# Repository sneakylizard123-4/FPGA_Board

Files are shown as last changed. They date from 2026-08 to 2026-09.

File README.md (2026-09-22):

# FPGA_Board

A iCE40 FPGA devboard

## Custom Features
- ICE40UP5K-SG48ITR FPGA (5280 LUTs, QFN-48)
- On-board FT232H flasher with EEPROM
- 16MB W25Q128JVS SPI flash
- USB-C with ESD protection
- RGB LED, green config-status LED, reset button
- 12MHz oscillator, 4-layer PCB

## PCB Design

The board is a 4-layer PCB.

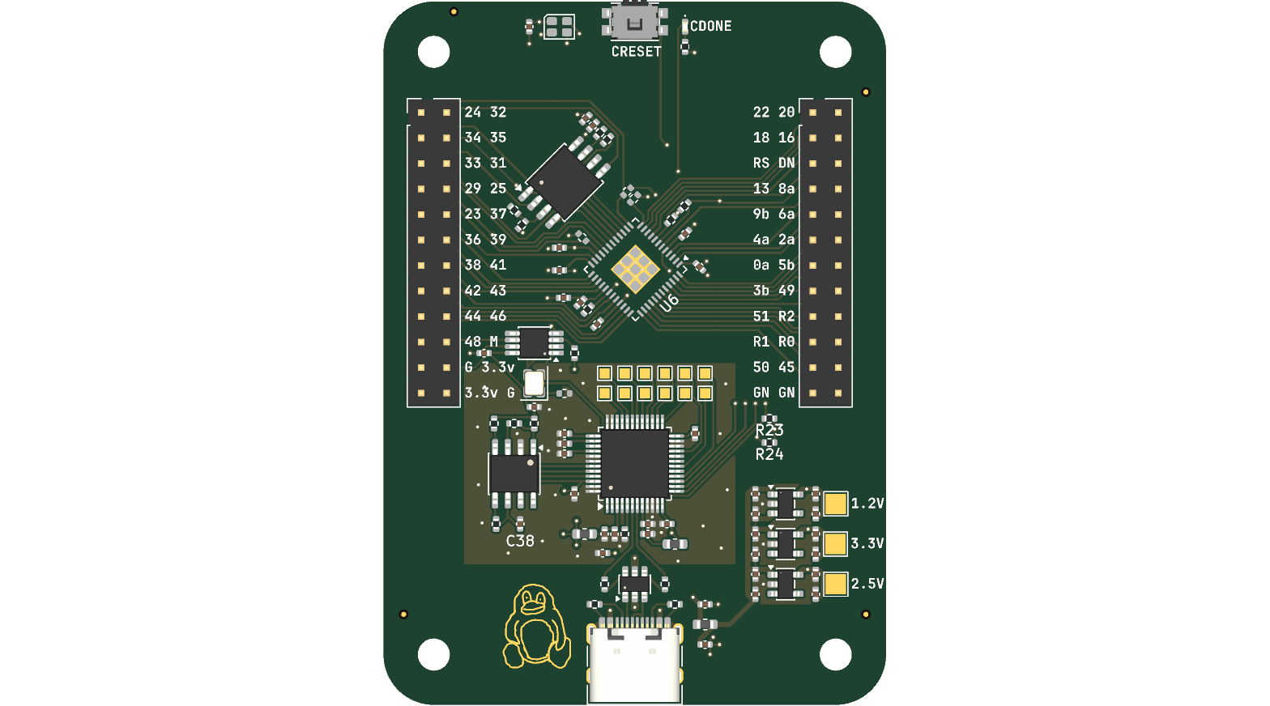
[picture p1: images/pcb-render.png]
PCB 3D / layout image


It is built around the Lattice iCE40 FPGA, designed to be programmed over USB through the on-board FT232H. The SPI flash boots the bitstream on power-up.
It is fully supported by the open-source yosys/nextpnr/icestorm flow.

## Firmware

As the board uses an iCE40 UltraPlus, it is programmed with yosys + nextpnr-ice40 + icepack + iceprog/icestorm.

## BOM

| Ref | Value | LCSC # | MPN | Manufacturer | Footprint | Qty | Unit $ | Ext $ | Link |
|-----|---|---|-----|---|---|-----|---|---|---|
| C1,C2,C3,C4,C5,C12,C13,C14,C17,C24,C34,C35 | 10uF 0402 | C307415 | - | - | 0402 | 12 | 0.1900 | 2.28 | [LCSC](https://www.lcsc.com/product-detail/C307415.html) |
| C6,C7,C8,C9,C10,C11,C15,C16,C18,C19,C20,C21,C22,C23,C25,C26,C27,C28,C29,C30,C31,C32,C33,C37,C38 | 100nF 0402 | C131394 | - | - | 0402 | 25 | 0.0096 | 0.24 | [LCSC](https://www.lcsc.com/product-detail/C131394.html) |
| C36 | 4.7uF 0402 | C21120 | - | - | 0402 | 1 | 0.0200 | 0.02 | [LCSC](https://www.lcsc.com/product-detail/C21120.html) |
| D1 | LED_ARGB PLCC4 | C2786 | - | - | LED_Cree-PLCC4_2x2mm_CW | 1 | 0.1300 | 0.13 | [LCSC](https://www.lcsc.com/product-detail/C2786.html) |
| D2 | Green LED 0402 | C2286 | - | - | 0402 | 1 | 0.0100 | 0.01 | [LCSC](https://www.lcsc.com/product-detail/C2286.html) |
| FB1,FB2,FB3 | Ferrite Bead 1.5k | C82155 | BLM18HE152SN1D | muRata | 0603 | 3 | 0.0300 | 0.09 | [LCSC](https://www.lcsc.com/product-detail/C82155.html) |
| J1 | USB-C Receptacle 14P | C165948 | TYPE-C-31-M-12 | Korean Hroparts Elec | USB-C | 1 | 0.1900 | 0.19 | [LCSC](https://www.lcsc.com/product-detail/C165948.html) |
| J3,J4 | Pin Header 2x12 2.54mm | C492423 | PZ254V-12-12P | XFCN | Through Hole | 2 | 0.0700 | 0.14 | [LCSC](https://www.lcsc.com/product-detail/C492423.html) |
| R1,R2 | 5.1k 1% 0402 | C25905 | 0402WGF5101TCE | UNI-ROYAL | 0402 | 2 | 0.0040 | 0.01 | [LCSC](https://www.lcsc.com/product-detail/C25905.html) |
| R3,R4 | 22R 1% 0402 | C23200 | - | - | 0402 | 2 | 0.0040 | 0.01 | [LCSC](https://www.lcsc.com/product-detail/C23200.html) |
| R5,R6,R10,R11,R19,R20,R21,R23,R24 | 10k 1% 0402 | C25904 | - | - | 0402 | 9 | 0.0040 | 0.04 | [LCSC](https://www.lcsc.com/product-detail/C25904.html) |
| R7 | 1k 1% 0402 | C25898 | - | - | 0402 | 1 | 0.0040 | 0.00 | [LCSC](https://www.lcsc.com/product-detail/C25898.html) |
| R8,R9,R14 | 0R 0402 | C25887 | - | - | 0402 | 3 | 0.0030 | 0.01 | [LCSC](https://www.lcsc.com/product-detail/C25887.html) |
| R12 | 100R 1% 0402 | C22861 | - | - | 0402 | 1 | 0.0040 | 0.00 | [LCSC](https://www.lcsc.com/product-detail/C22861.html) |
| R18 | 12k 1% 0402 | C25913 | - | - | 0402 | 1 | 0.0040 | 0.00 | [LCSC](https://www.lcsc.com/product-detail/C25913.html) |
| R22 | 2.2k 1% 0402 | C25901 | - | - | 0402 | 1 | 0.0040 | 0.00 | [LCSC](https://www.lcsc.com/product-detail/C25901.html) |
| SW1 | Tactile Switch EVQPUD | C158289 | EVQPUM | PANASONIC | SMD | 1 | 0.2000 | 0.20 | [LCSC](https://www.lcsc.com/product-detail/C158289.html) |
| U1 | USBLC6-2SC6 | C7519 | USBLC6-2SC6 | ST | SOT-23-6 | 1 | 0.1800 | 0.18 | [LCSC](https://www.lcsc.com/product-detail/C7519.html) |
| U2 | TLV75712PDBV | C485515 | TLV75712PDBVR | TI | SOT-23-5 | 1 | 0.1800 | 0.18 | [LCSC](https://www.lcsc.com/product-detail/C485515.html) |
| U3 | TLV75725PDBV | C485516 | TLV75725PDBVR | TI | SOT-23-5 | 1 | 0.1800 | 0.18 | [LCSC](https://www.lcsc.com/product-detail/C485516.html) |
| U4 | TLV75733PDBV | C485517 | TLV75733PDBVR | TI | SOT-23-5 | 1 | 0.1800 | 0.18 | [LCSC](https://www.lcsc.com/product-detail/C485517.html) |
| U5 | 74AUC2G240 | C2652105 | - | - | VSSOP-8 | 1 | 0.7200 | 0.72 | [LCSC](https://www.lcsc.com/product-detail/C2652105.html) |
| U6 | ICE40UP5K-SG48ITR | C2678152 | ICE40UP5K-SG48ITR | Lattice | QFN-48 | 1 | 8.5600 | 8.56 | [LCSC](https://www.lcsc.com/product-detail/C2678152.html) |
| U7 | W25Q128JVS | C113767 | W25Q128JVS | Winbond | SOIC-8 | 1 | 2.5200 | 2.52 | [LCSC](https://www.lcsc.com/product-detail/C113767.html) |
| U8 | FT232H | C51997 | FT232HL | FTDI | LQFP-48 | 1 | 10.6200 | 10.62 | [LCSC](https://www.lcsc.com/product-detail/C51997.html) |
| U9 | 93LC56BT-I/OT | C190271 | 93LC56BT-I/OT | Microchip | SOIC-8 | 1 | 0.4500 | 0.45 | [LCSC](https://www.lcsc.com/product-detail/C190271.html) |
| Y1 | SG-210STF 12MHz | C17426037 | SG-210STF | Seiko Epson | 2.5x2.0mm | 1 | 0.3700 | 0.37 | [LCSC](https://www.lcsc.com/product-detail/C17426037.html) |
| PCB | Bare PCB | — | — | — | 50x70mm | 1 | 20.0000 | 20.00 | — |
| STENCIL | Top stencil | — | — | — | 100x150mm | 1 | 18.0000 | 18.00 | — |
| **Total** | — | — | — | — | — | **79** | — | **65.33** | — |

Full CSVs: [LCSC BOM](BOM.csv)
[KiCad generated BOM](kicad/production/bom.csv)
[Pick and place](kicad/production/positions.csv)

## Production

Production files in [Prod Files](kicad/production/)
This board assumes JLCPCB's standard 4 layer
- HASL Lead Free
- 1.6mm thick board

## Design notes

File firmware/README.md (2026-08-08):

# FPGA_Board firmware (ICE40UP5K)

Open-source iceStorm flow: `yosys` -> `nextpnr-ice40` -> `icepack` -> `iceprog`.

## Proof-of-life: RGB rainbow

`rtl/rainbow.v` cycles the on-board common-anode RGB LED through the color
wheel. The hue advances 25x/second, so one lap takes 10 seconds.

## Pin map

| Signal | FPGA pin | Net | Note |
|---|---|---|---|
| clk_12m| 20 | IOB_25b_G3 | 12 MHz clock |
| rgb_r  | 39 | RGB0 | open-drain, active low |
| rgb_g  | 40 | RGB1 | open-drain, active low |
| rgb_b  | 41 | RGB2 | open-drain, active low |

The RGB LED (D1) is common-anode to 3.3 V, so its cathodes are driven
active-low directly by the FPGA. The green LED (D2) is wired to `CDONE`
(config-done indicator), not a user GPIO. SW1 pulls `CRESET` (pin 8) low.

## Build

```sh
make
```

## Program flash (iceprog)

```sh
make prog
```

`iceprog` uses the FT2232H via the SPI header (J3.2-5: FPGA_SO/FPGA_SI/
FT_SCK/FT_CS). After programming, toggle the FT_CS/MODE pins or press
SW1/cycle power to reconfigure from the W25Q128.

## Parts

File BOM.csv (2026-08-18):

Designator | Footprint | Quantity | Value | LCSC Part # | MOQ | Unit Price | Total Cost | Amount
C1, C2, C3, C4, C5, C12, C13, C14, C17, C24, C34, C35 | Capacitor_SMD:C_0402_1005Metric | 12 | 10uF | C307415 | 5 | $0.1900 | $2.28 | 12
C6, C7, C8, C9, C10, C11, C15, C16, C18, C19, C20, C21, C22, C23, C25, C26, C27, C28, C29, C30, C31, C32, C33, C37, C38 | Capacitor_SMD:C_0402_1005Metric | 25 | 0.1uF | C131394 | 100 | $0.0096 | $0.96 | 100
C36 | Capacitor_SMD:C_0402_1005Metric | 1 | 4.7uF | C21120 | 5 | $0.0200 | $0.10 | 5
D1 | LED_SMD:LED_Cree-PLCC4_2x2mm_CW | 1 | LED_ARGB | C2786 | 5 | $0.1300 | $0.65 | 5
D2 | LED_SMD:LED_0402_1005Metric | 1 | GREEN | C2286 | 5 | $0.0100 | $0.05 | 5
FB1, FB2, FB3 | Inductor_SMD:L_0603_1608Metric | 3 | BLM18HE152SN1D | C82155 | 10 | $0.0300 | $0.30 | 10
J1 | Connector_USB:USB_C_Receptacle_HRO_TYPE-C-31-M-12 | 1 | USB_C_Receptacle_USB2.0_14P | C165948 | 5 | $0.1900 | $0.95 | 5
J3, J4 | Connector_PinHeader_2.54mm:PinHeader_2x12_P2.54mm_Vertical | 2 | Conn_02x12_Odd_Even | C492423 | 10 | $0.0700 | $0.70 | 10
R1, R2 | Resistor_SMD:R_0402_1005Metric | 2 | 5.1k | C25905 | 100 | $0.0040 | $0.40 | 100
R3, R4 | Resistor_SMD:R_0402_1005Metric | 2 | 22 | C23200 | 100 | $0.0040 | $0.40 | 100
R5, R6, R10, R11, R19, R20, R21, R23, R24 | Resistor_SMD:R_0402_1005Metric | 9 | 10k | C25904 | 100 | $0.0040 | $0.40 | 100
R7 | Resistor_SMD:R_0402_1005Metric | 1 | 1k | C25898 | 100 | $0.0040 | $0.40 | 100
R8, R9, R14 | Resistor_SMD:R_0402_1005Metric | 3 | 0R | C25887 | 100 | $0.0030 | $0.30 | 100
R12 | Resistor_SMD:R_0402_1005Metric | 1 | 100 | C22861 | 100 | $0.0040 | $0.40 | 100
R18 | Resistor_SMD:R_0402_1005Metric | 1 | 12k | C25913 | 100 | $0.0040 | $0.40 | 100
R22 | Resistor_SMD:R_0402_1005Metric | 1 | 2.2k | C25901 | 100 | $0.0040 | $0.40 | 100
SW1 | Button_Switch_SMD:Panasonic_EVQPUM_EVQPUD | 1 | SW_Push | C158289 | 1 | $0.2000 | $0.20 | 1
U1 | Package_TO_SOT_SMD:SOT-23-6 | 1 | USBLC6-2SC6 | C7519 | 5 | $0.1800 | $0.90 | 5
U2 | Package_TO_SOT_SMD:SOT-23-5 | 1 | TLV75712PDBV | C485515 | 5 | $0.1800 | $0.90 | 5
U3 | Package_TO_SOT_SMD:SOT-23-5 | 1 | TLV75725PDBV | C485516 | 5 | $0.1800 | $0.90 | 5
U4 | Package_TO_SOT_SMD:SOT-23-5 | 1 | TLV75733PDBV | C485517 | 5 | $0.1800 | $0.90 | 5
U5 | Package_SO:VSSOP-8_3x3mm_P0.65mm | 1 | 74AUC2G240 | C2652105 | 1 | $0.7200 | $0.72 | 1
U6 | Package_DFN_QFN:QFN-48-1EP_7x7mm_P0.5mm_EP5.6x5.6mm | 1 | ICE40UP5K-SG48ITR | C2678152 | 1 | $8.5600 | $8.56 | 1
U7 | Package_SO:SOIC-8_5.3x5.3mm_P1.27mm | 1 | W25Q128JVS | C113767 | 12 | $2.5200 | $30.24 | 12
U8 | Package_QFP:LQFP-48_7x7mm_P0.5mm | 1 | FT232H | C51997 | 1 | $10.6200 | $10.62 | 1
U9 | Package_SO:SOIC-8_3.9x4.9mm_P1.27mm | 1 | 93LC56BT-I/OT | C190271 | 5 | $0.4500 | $2.25 | 5
Y1 | Oscillator:Oscillator_SMD_SeikoEpson_SG210-4Pin_2.5x2.0mm | 1 | SG-210STF | C17426037 | 1 | $0.3700 | $0.37 | 1
PCB |  | 1 | 50x70mm Purple 1.6mm LeadFree HASL 100x150mm panel |  |  |  | $20.00 | 1
STENCIL |  | 1 | Top 100x150mm No-Framework |  |  |  | $18.00 | 1
TOTAL |  |  | Components: $65.65 | PCB: $20 | Stencil: $18 | GRAND TOTAL: $103.65

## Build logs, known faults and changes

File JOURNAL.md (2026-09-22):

---
title: "FPGA Board"
author: sneak
description: "iCE40 UltraPlus FPGA development board with on-board FT232H flasher and SPI flash boot"
created_at: "2026-08-07T00:00:00Z"
---

# August 7: project start

## What I did

- started the fpga board project
- picked the ice40 up5k as the fpga
- decided on a devboard layout with headers breaking out the io instead of a bare module

## Why

- wanted a fpga to experiment with, but without a bga/lga footprint i could never hand solder
- the whole icestorm toolchain is open source (yosys + nextpnr + icepack), no proprietary ide
- 5280 luts, built in rgb drive pins, and a qfn-48 package i can actually solder

## Screenshots

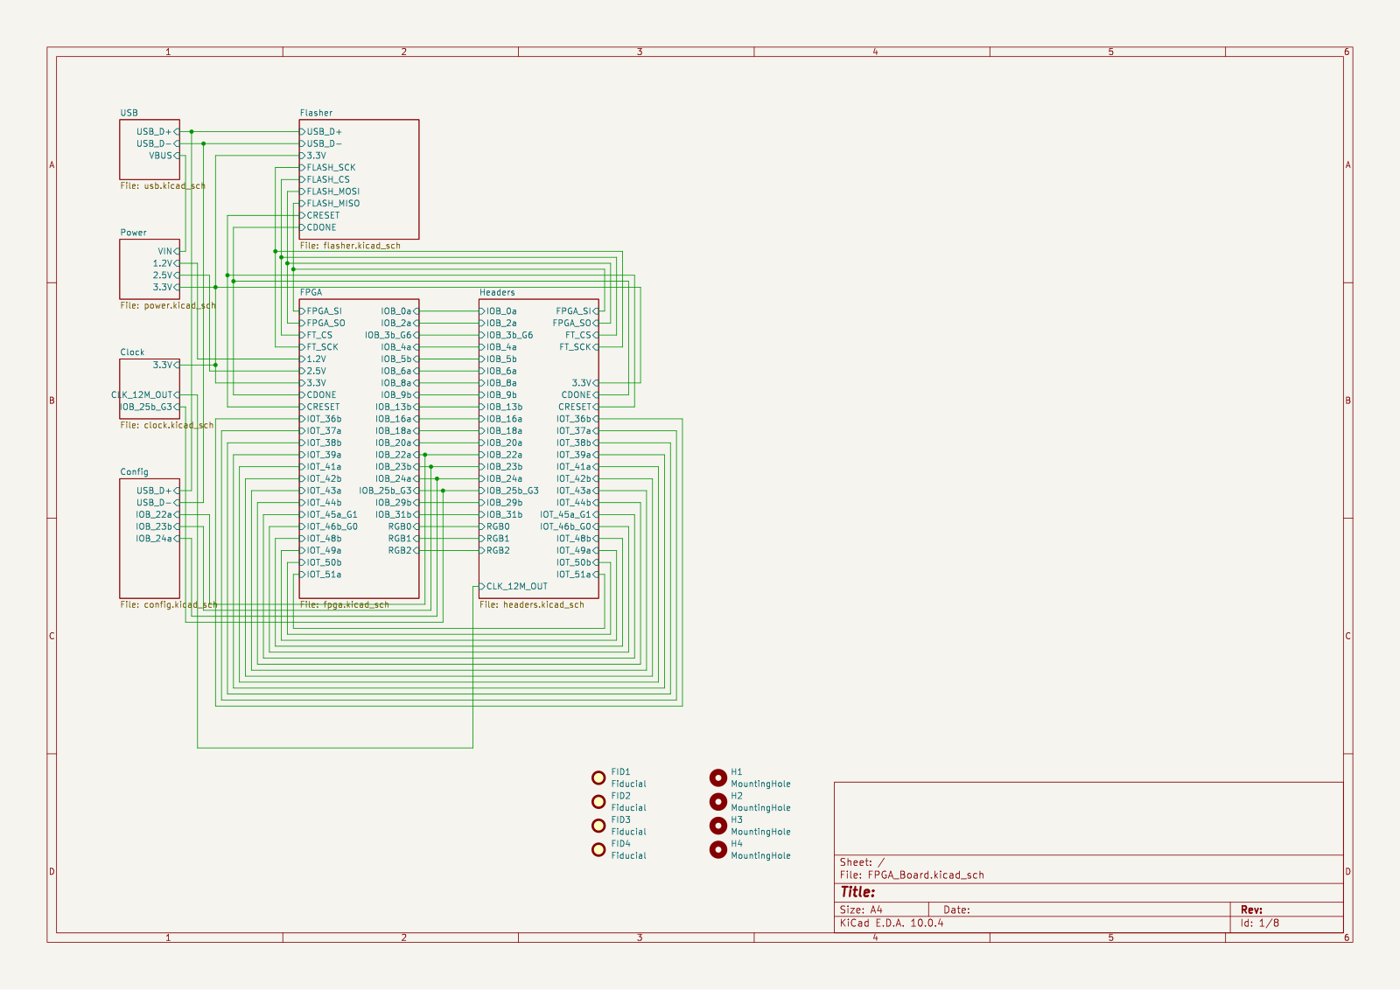
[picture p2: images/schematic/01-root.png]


**Total time spent: 3 hours**

---

# August 7: tinyfpga boot mode

## What I did

- added config sheet
- added tinyfpga features
- added the config sheet with the strap resistors that pick the boot source - on-board spi flash, or direct load over the flasher
- super simple sheet with just 3 resistors

## Why

- the tinyfpga is the most well known ice40 board and lots of tutorials use it, wanted my board to be able to act like one
- second boot mode just in case

## Screenshots

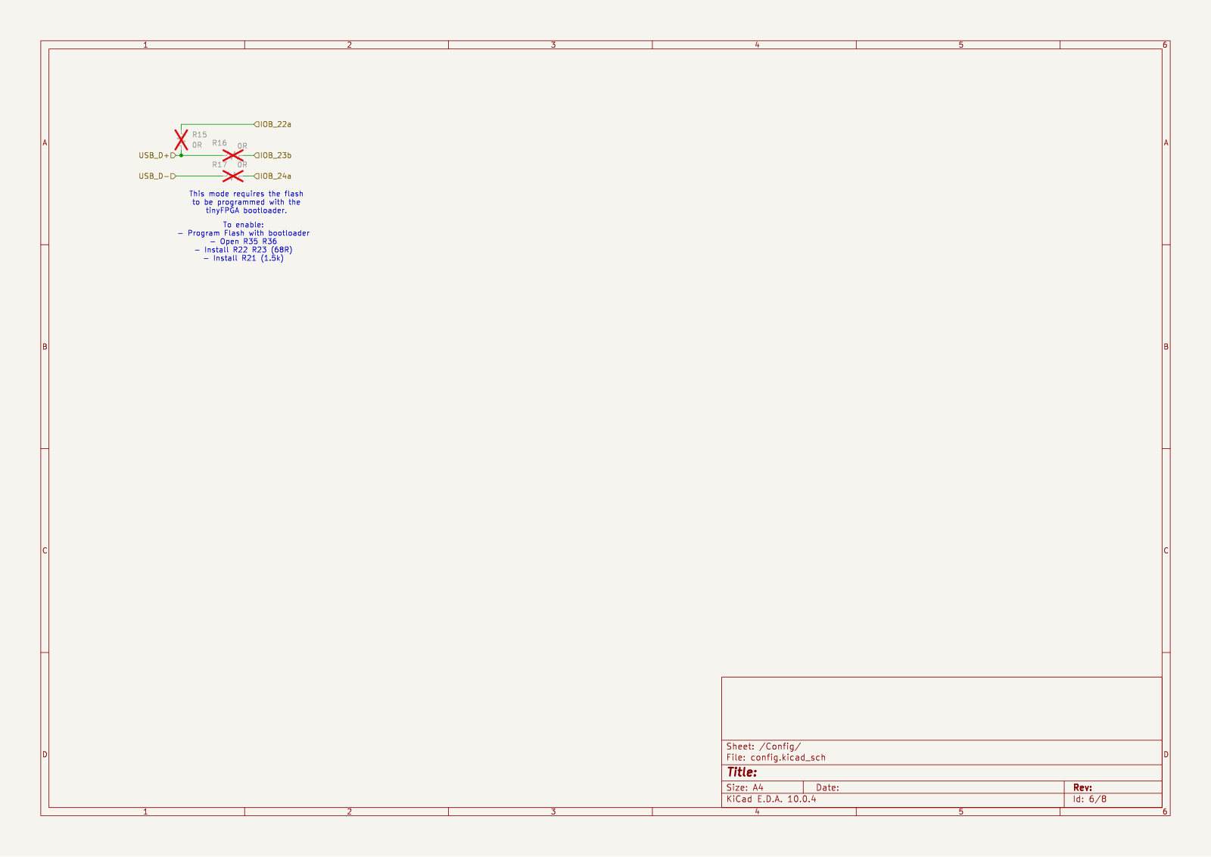
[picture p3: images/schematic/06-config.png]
config


**Total time spent: 3 hours**

---

# August 8: schematic - usb and power

## What I did

- started the usb and power sheets
- added the usb-c with an esd clamp on the data lines
- three rails (1.2v, 2.5v, 3.3v), each from its own ldo stepping down from usb 5v
- ferrite beads on each rail to keep noise out
- beefed up the copper so the board can handle the current

## Why

- the whole board is powered off the usb-c
- the ice40 needs three separate voltages
- esd clamp so a bad cable or a zap cant kill the fpga
- ldos because we dont need that much power

## Screenshots

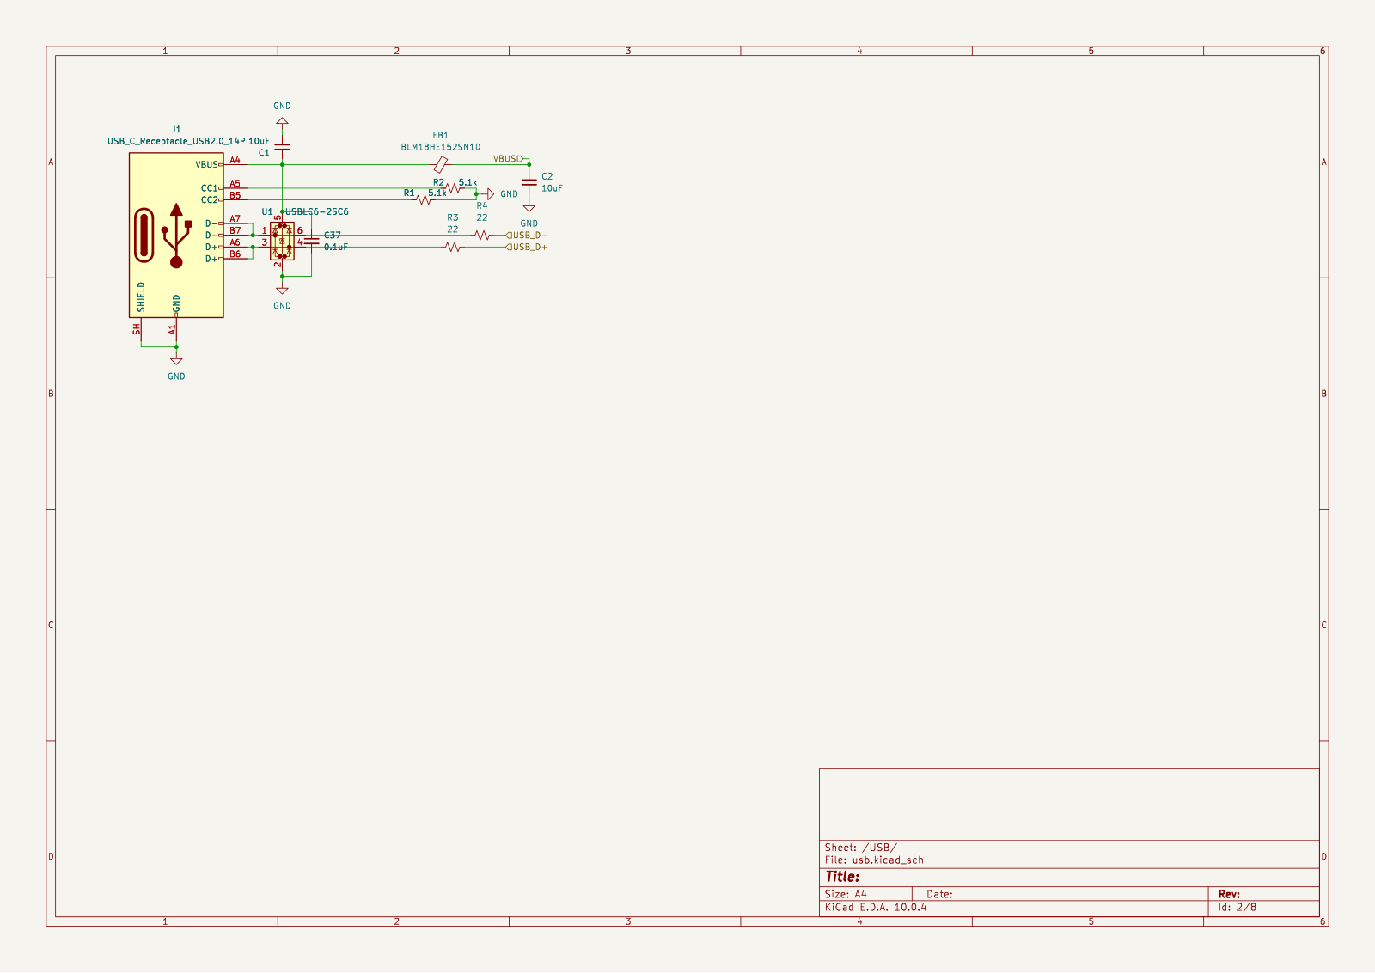
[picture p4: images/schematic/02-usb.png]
usb

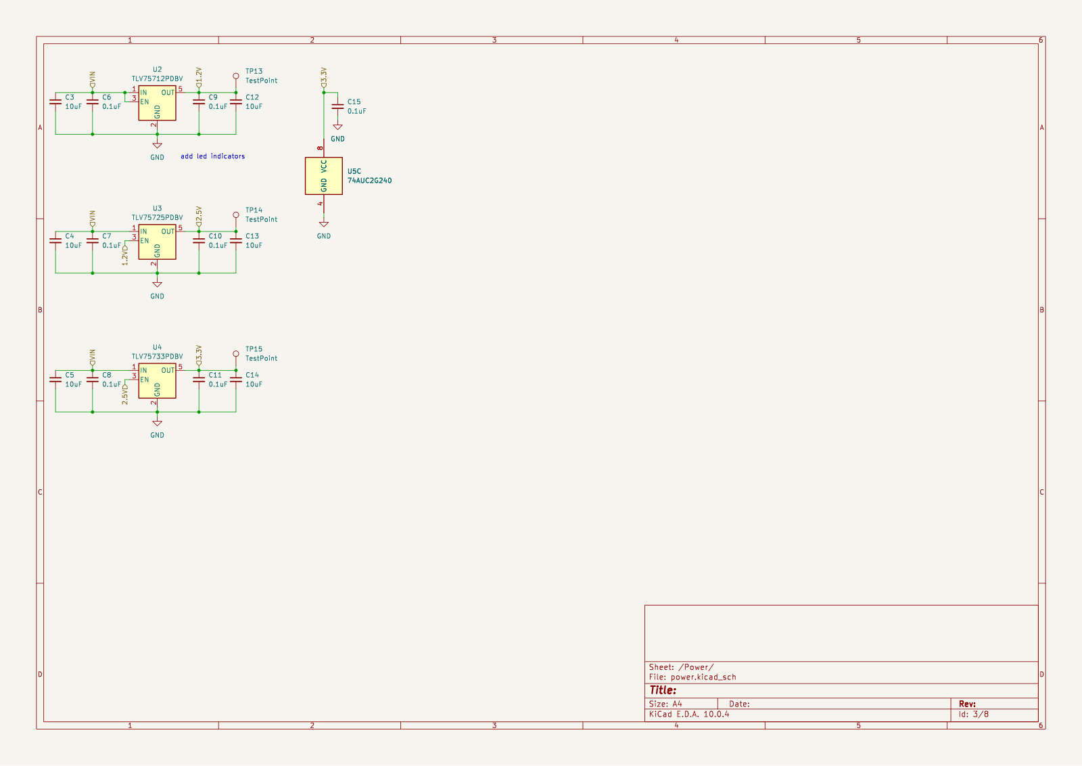
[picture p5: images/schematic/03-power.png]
power


**Total time spent: 4 hours**

---

# August 8: schematic - fpga core

## What I did

- started the iCE40 sheet, the main fpga
- added decoupling caps on the power pins and the reset button on creset
- wired the rgb led to the up5k's rgb pins (39, 40, 41)
- added a green cdone led to show config status
- added spi flash

## Why

- the support stuff the datasheet wants
- the rgb pins are open-drain active-low, so they need a common-anode led
- cdone led so i can see at a glance whether the bitstream actually loaded
- spi flash for boot

## Screenshots

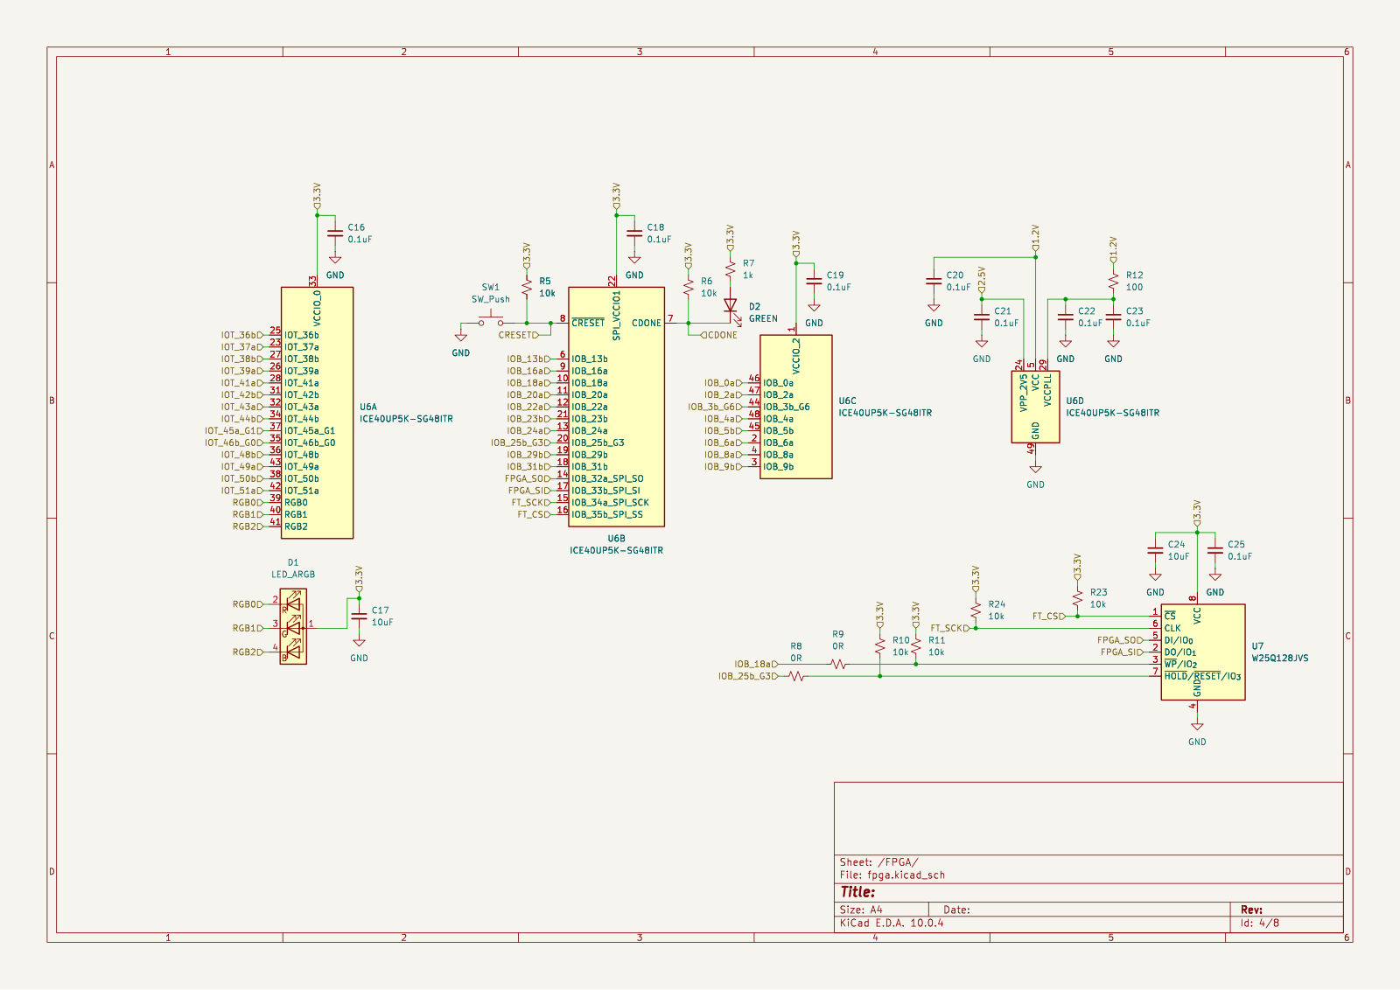
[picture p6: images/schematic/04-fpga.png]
fpga


**Total time spent: 5 hours**

---

# August 9: schematic - clock, flasher, headers

## What I did

- clock sheet: 12mhz buffered oscillator
- flasher sheet: ft232h with its own eeprom to store the mpsse config
- broke the io out on two 2x12 headers with pullups on the flash cs and sclk signals

## Why

- clock deliberately boring so nothing can break
- 6 parts in clock sheet
- ft232h lets the board program itself over usb without an external programmer, the eeprom setup was the confusing part and ate most of the day
- so many pins to route on the ft232h, most of them went to test pads
- spi has di and do but we combine them into one
- headers left and right of the fpga so we can hopefully make shields soon if the project works

## Screenshots

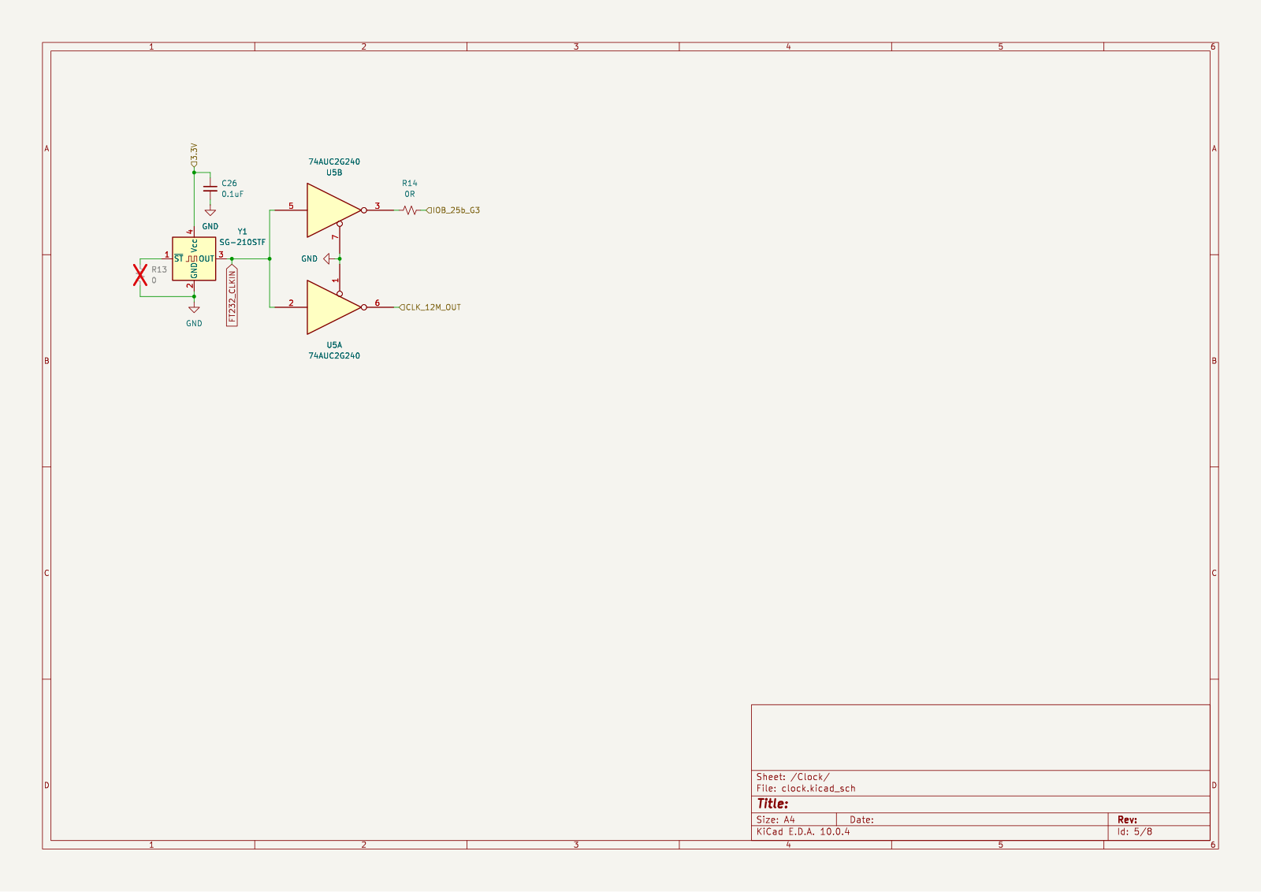
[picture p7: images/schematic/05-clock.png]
clock

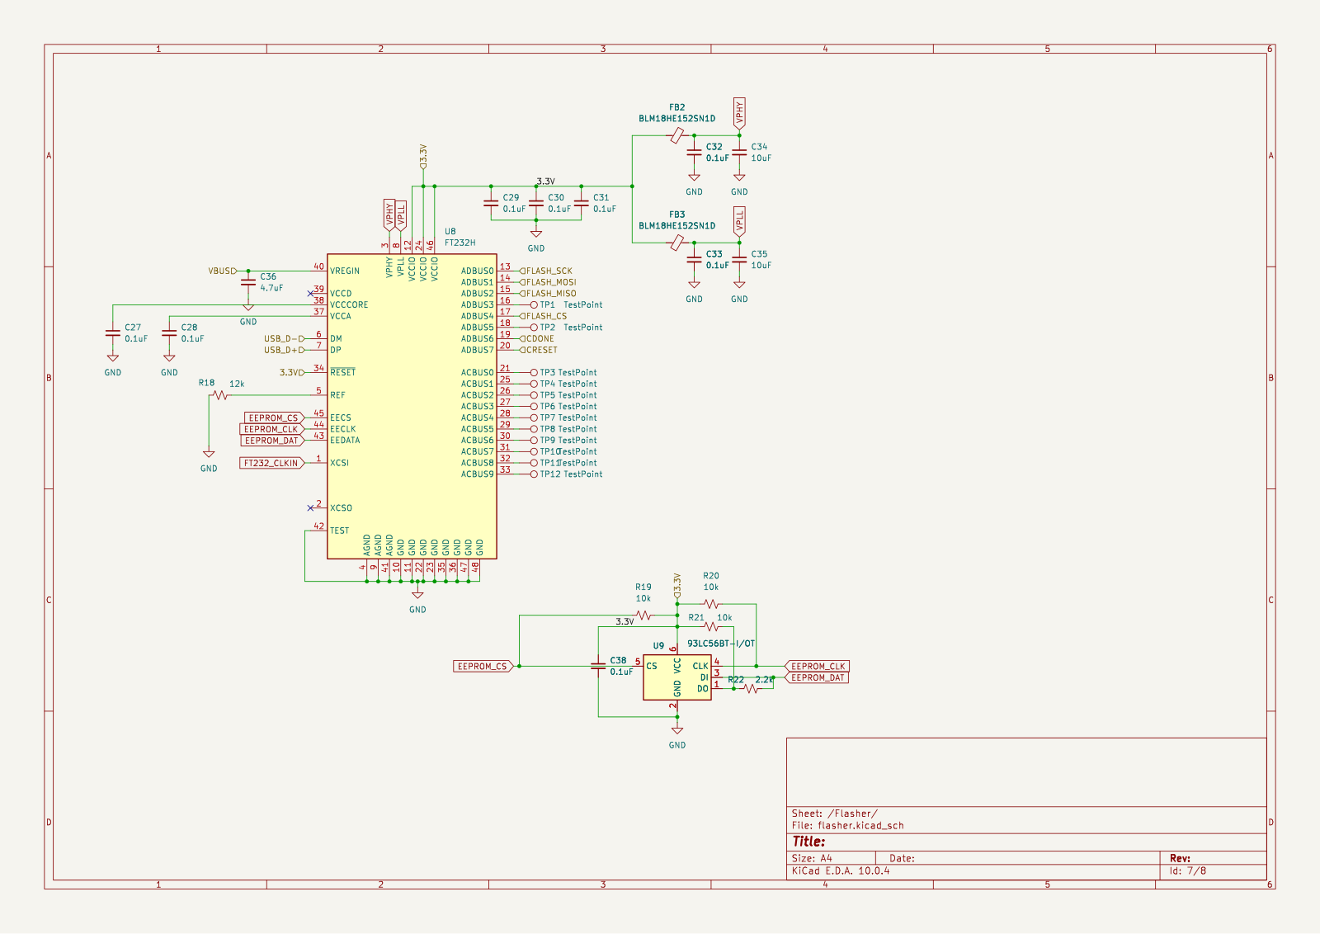
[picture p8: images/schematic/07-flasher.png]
flasher

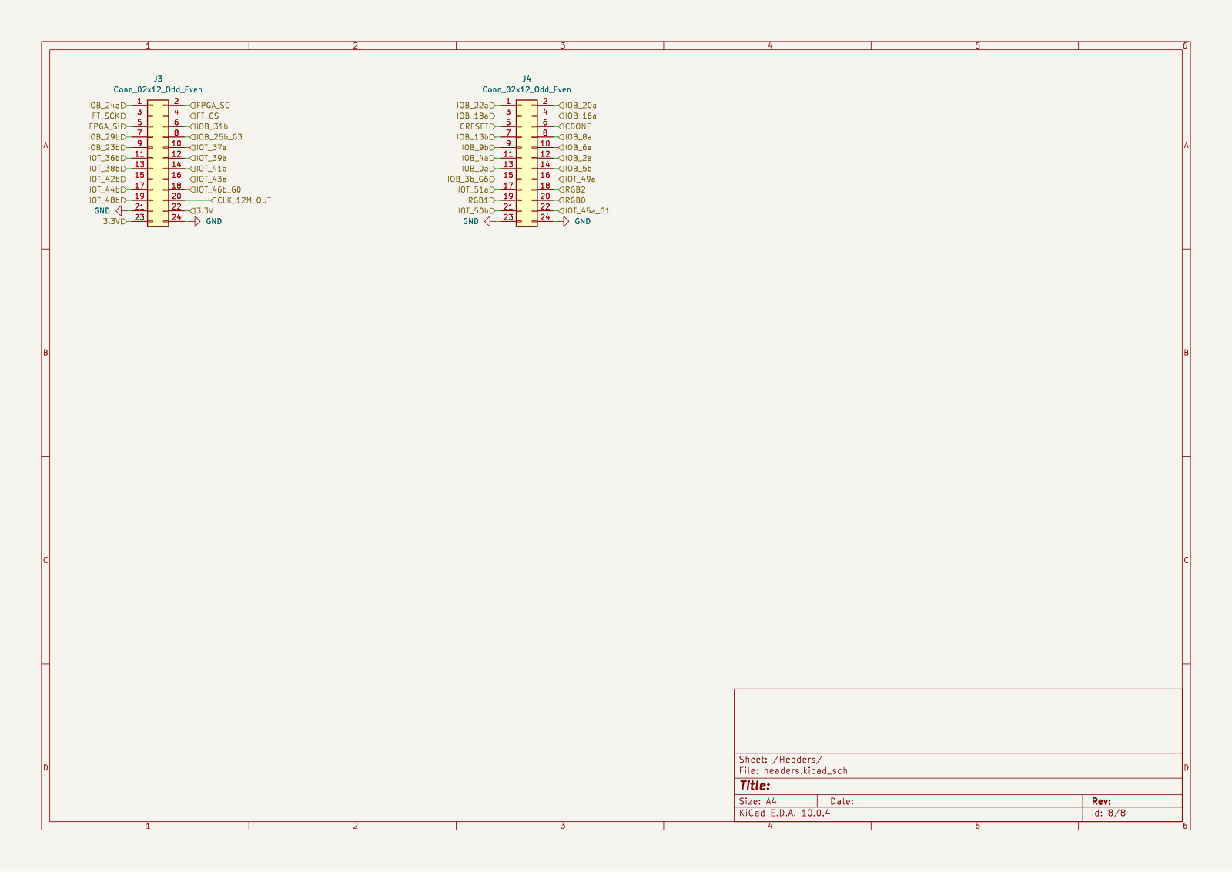
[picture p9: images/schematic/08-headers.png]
headers


**Total time spent: 6 hours**

---

# August 10: schematic review

## What I did

- reviewed the schematic and cleaned up unnecessary stuff
- removed some strap resistors that were included twice
- tidied up the net labels and made the whole thing presentable

## Why

- getting it clean before sending it out for external feedback
- schematic looked a bit messy

## Screenshots

root schematic

**Total time spent: 2 hours**

---

# August 11: pcb start

## What I did

- started the pcb, 50x70mm with m3 mounting holes 5mm from the edges
- usb-c on the bottom 50mm edge, headers to the left and right of the fpga
- fpga center-top with the ft232h below it
- started the via fanout to get the qfn signals out

## Why

- headers on both sides so shields can slot in
- usb on bottom middle, like my other boards

## Screenshots

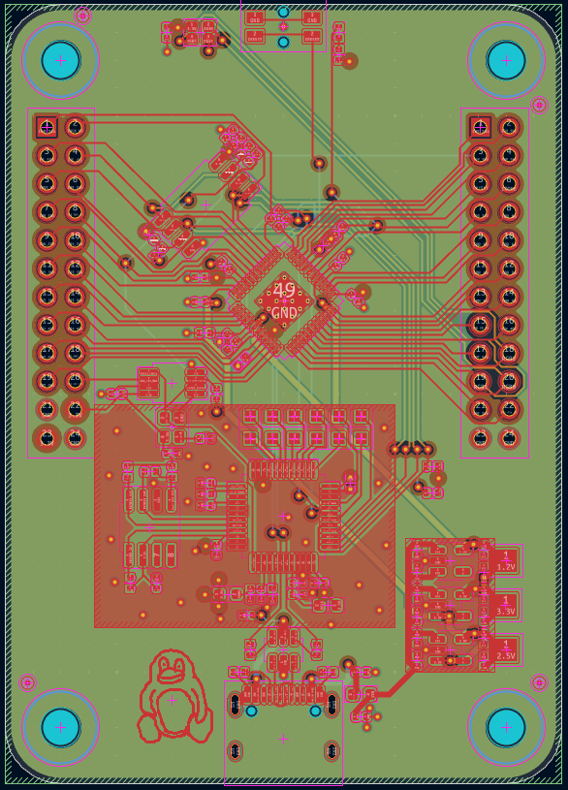
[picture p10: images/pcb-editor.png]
pcb


**Total time spent: 3 hours**

---

# August 12: firmware - rainbow proof of life

## What I did

- asked a friend to help with the verilog, never written an fpga design before
- got the icestorm flow running (yosys -> nextpnr -> icepack)
- simple rainbow demo that cycles the rgb led
- timing passes at 12mhz with plenty of headroom

## Why

- proof of life before spending money on boards, cheapest way to find out the toolchain works
- rainbow might be one of the easiest tests, cos i dont need external hardware

## Screenshots

rainbow

**Total time spent: 2 hours**

---

# August 13: production files and fab order

## What I did

- generated the drill files for jlcpcb
- 50x70 4-layer 1.6mm board with rounded corners in purple
- used via in pad on the fpga to save space

## Why

- jlcpcb for cheap fab
- via in pad saves space (and i will regret it later)

## Screenshots

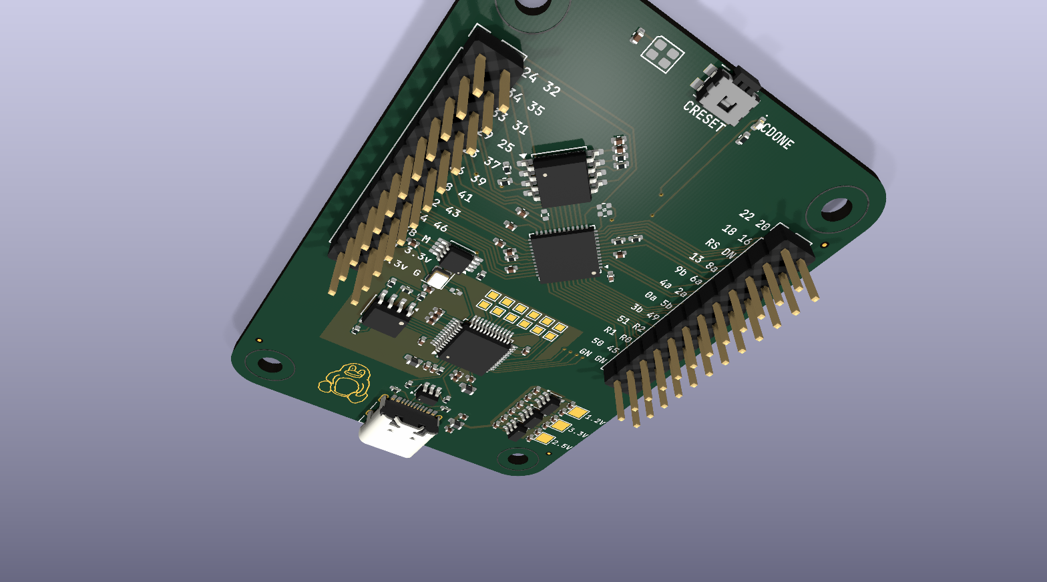
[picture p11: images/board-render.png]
board render


**Total time spent: 1 hour**

---

# August 13: schematic review - external feedback

## What I did

- sent the schematic out for review
- fixed r3/r4 (usb data resistors): 5.1k -> 22
- added the missing decoupling caps on a couple of parts
- added 10k pullups on flash cs and sclk (r23/r24)
- updated the bom with lcsc part numbers

## Why

- r3/r4 were 5.1k by accident
- power sequencing delay: fine for now, becomes an issue with bigger fpgas
- 10k cs pullups to prevent accidental chip selection

## Screenshots

editor

**Total time spent: 3 hours**

---

# August 25: through-hole vias out of pads

## What I did

- finally came back to the via in pad problem
- swapped the fpga footprint to one with a smaller exposed pad, 5.6x5.6 down to 3.5x3.5
- shouldnt affect fpga performance too much
- re-fanned the fpga with the vias moved out of the pad and into the pad ring

## Why

- jlcpcb charges extra for via in pad and it's a pain for assembly
- smaller exposed pad means the vias can live in the pad ring instead of through the pad
- found the footprint thanks to an instagram reel rabbit hole
- cleaner traces = less clutter

## Screenshots

pcb editor

**Total time spent: 4 hours**

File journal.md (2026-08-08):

---
title: "FPGA Board"
author: sneak
description: "iCE40 UltraPlus FPGA development board with on-board FT232H flasher and SPI flash boot"
created_at: "2026-08-07T00:00:00Z"
---

# August 7: project start and component selection

started the fpga board project. wanted a small dev board around the lattice ice40 ultraplus - it packs a real amount of logic into a tiny qfn-48 and the open-source yosys/nextpnr/icestorm flow means i dont have to fight a vendor toolchain. also wanted it self-contained so i can program it over usb without dragging a programmer around.

picked the ice40up5k-sg48itr specifically. 5280 luts, 1.2v core, and the rgb0-2 pins can sink enough current to drive an rgb led directly, which is a neat trick for a tiny board.

the big decision was programming. most tiny fpga boards either use an external programmer or a jtag header. i wanted it all on board, so an ft232h over spi it is - it doubles as a general usb bridge if i ever need one. 16mb w25q128jvs flash for the boot bitstream.

set up the kicad project as hierarchical sheets so each block stays manageable - usb, power, fpga, clock, config, flasher, headers.
root schematic

**Total time spent: 3 hours**

# August 7: tinyfpga boot mode

spent the afternoon on the boot/config question. wrote out a tinyfpga bx compatible mode as a separate design note sheet (tinyfpga.kicad_sch) so i could think through it before committing to the strap resistors.

the idea: the flash can hold either a raw bitstream (spi master mode, the default) or the tinyfpga bootloader, which lets the ft232h push bitstreams straight over usb without reflashing the flash every time. switching between them is just a few 0-ohm straps - r16/r17/r18 on the config sheet.

for the bootloader path the serial resistors need to change (68r on the data lines, 1.5k pull on one of them), so i left those as install-options rather than stuffing them by default. it means the board can do both without a board respin.
config

**Total time spent: 3 hours**

# August 8: schematic - usb and power

did the usb sheet first. usb-c receptacle for usb2.0, two 5.1k cc pulldowns so it presents as a device. usblc6-2sc6 esd clamp on the data lines, ferrite bead on vbus. two 10uf bulk caps at the connector.

power sheet next. three tlv757 ldos off the 5v rail - 1.2v for the fpga core, 2.5v for the vpp/io banks, 3.3v for the io, flash, and ft232h. decoupling on every rail. added a couple of 74auc2g240 dual buffers to translate between the 3.3v and 1.2v domains on the clock and config paths - the ice40's spi pins can run at a lower voltage and the ucsi buffer keeps the levels clean.
usb
power

**Total time spent: 4 hours**

# August 8: schematic - fpga core

the fpga sheet. ice40up5k in qfn-48 with the exposed pad on ground, decoupling caps against every power pin. vpp_2v5 for the sram configuration. wired the rgb0/1/2 open-drain pins to the argb led through series resistors, plus a plain green status led.

reset button with a 10k pullup, cdone pulled up. the w25q128jvs spi flash sits right next to the fpga's dedicated spi pins (io32-35). spent a while on the flash pin ordering - the ice40 has specific pins for spi_si/so/sck/ss in master mode and it was easy to swap two of them if i wasnt careful.

the si/so lines to the flash also branch off toward the config sheet so the ft232h can either own the flash (bootloader mode) or stay out of the way.
fpga

**Total time spent: 5 hours**

# August 8: schematic - clock, flasher, headers

clock sheet is simple - a 12mhz sg-210stf oscillator through a 74auc2g240 buffer to the fpga, plus a copy of the clock to the ft232h so the bridge is clocked too.
clock

flasher sheet is the biggest. ft232h in lqfp-48 with a 93lc56bt eeprom on its mpsse config pins, 12 test points scattered along the spi and control lines, ferrite-filtered power, and the usual decoupling mess. the ft232h was actually pretty involved - 48 pins, most of them nc or needing to be tied to a known state. went through the datasheet pin by pin so nothing floats.
flasher

headers sheet - two 2x24 pin header breaking out the io pins. the ice40 has a bunch of io pairs (iob_* and iot_* pins) and routing them all to two tidy connectors keeps the board useful as a general fpga breakout.
headers

**Total time spent: 6 hours**

# August 8: schematic review

full review of all sheets, ran erc. caught a couple of net-name mismatches between the fpga and config sheets (the same signal with two names) and a dangling label on the flasher. fixed them, erc is clean now.

the r16/r17/r18 strap designators also show up on the tinyfpga note sheet which is confusing when reading the schematic - theyre the same physical resistors so its intentional, but i might rename the note sheet's copies later to make it less confusing.
root schematic

**Total time spent: 2 hours**

# August 8: pcb start

imported the netlist and set up the board. 2-layer, 50x70mm with rounded corners - plenty of room for a qfn-48 fpga and a header on the edge. drew the edge cuts with the corner arcs so it feels like a proper product board and not a rectangle.

placed the big stuff - usb-c on one edge, header on the opposite so it can sit on a breadboard or dock edge-to-edge. fpga in the middle with the flash right beside it, ft232h on its own side away from the fpga. started the fanout.

still routing, but the placement feels good so far. the trick will be keeping the spi lines short and the 1.2v rail clean.
pcb

**Total time spent: 3 hours**

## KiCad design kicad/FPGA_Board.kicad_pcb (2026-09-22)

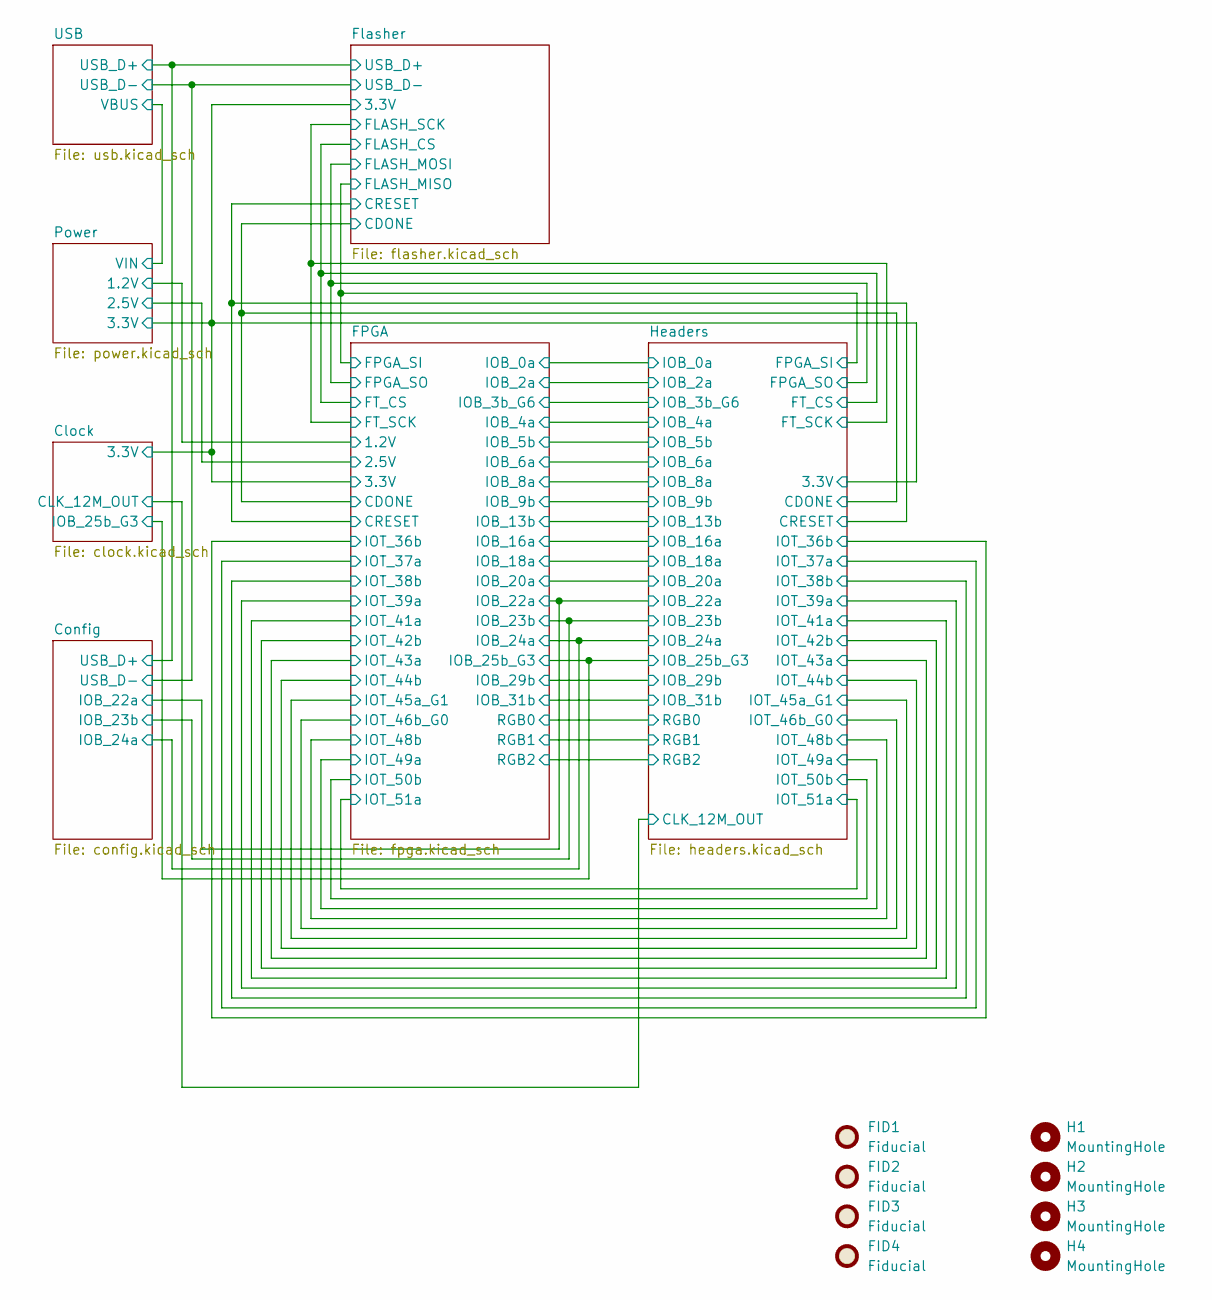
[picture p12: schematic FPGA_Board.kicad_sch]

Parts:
FID1, FID2, FID3, FID4: Fiducial; Fiducial_0.5mm_Mask1mm
H1, H2, H3, H4: MountingHole; MountingHole_3.2mm_M3

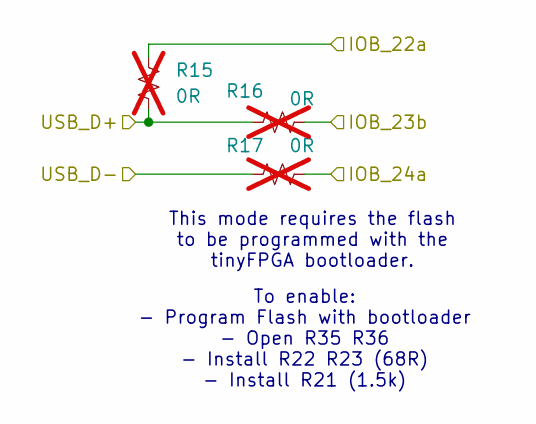
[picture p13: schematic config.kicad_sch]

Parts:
R15, R16, R17: 0R; R_0402_1005Metric; not fitted

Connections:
/Config/IOB_22a: R15.2; also elsewhere on the board
/Config/IOB_23b: R16.2; also elsewhere on the board
/Config/IOB_24a: R17.2; also elsewhere on the board
/Config/USB_D+: R15.1, R16.1; also elsewhere on the board
/Config/USB_D-: R17.1; also elsewhere on the board

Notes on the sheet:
This mode requires the flash to be programmed with the tinyFPGA bootloader.
To enable: - Program Flash with bootloader - Open R35 R36 - Install R22 R23 (68R) - Install R21 (1.5k)

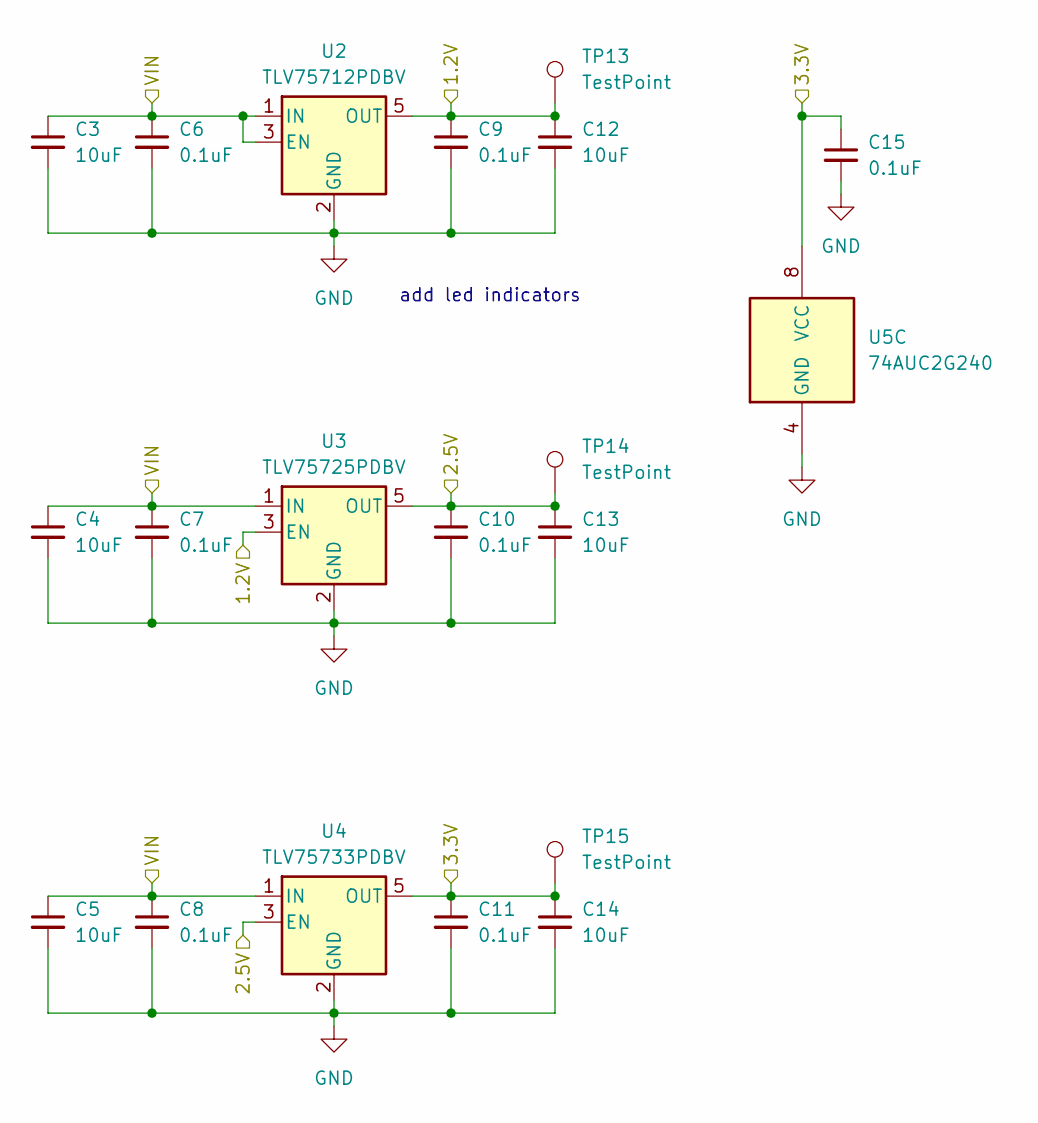
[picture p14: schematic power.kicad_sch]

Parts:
C3, C4, C5, C12, C13, C14: 10uF; C_0402_1005Metric
C6, C7, C8, C9, C10, C11, C15: 0.1uF; C_0402_1005Metric
TP13, TP14, TP15: TestPoint; TestPoint_Pad_2.0x2.0mm
U2: TLV75712PDBV; SOT-23-5
U3: TLV75725PDBV; SOT-23-5
U4: TLV75733PDBV; SOT-23-5
U5: 74AUC2G240; VSSOP-8_3x3mm_P0.65mm

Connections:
/FPGA/1.2V: C9.1, C12.1, TP13.1 (1_1), U2.5 (OUT), U3.3 (EN); also elsewhere on the board
/FPGA/2.5V: C10.1, C13.1, TP14.1 (1_1), U3.5 (OUT), U4.3 (EN); also elsewhere on the board
/Flasher/3.3V: C11.1, C14.1, C15.1, TP15.1 (1_1), U4.5 (OUT), U5.8 (VCC); also elsewhere on the board
/Power/VIN: C3.1, C4.1, C5.1, C6.1, C7.1, C8.1, U2.1 (IN), U2.3 (EN), U3.1 (IN), U4.1 (IN); also elsewhere on the board
GND: C3.2, C4.2, C5.2, C6.2, C7.2, C8.2, C9.2, C10.2, C11.2, C12.2, C13.2, C14.2, C15.2, U2.2 (GND), U3.2 (GND), U4.2 (GND), U5.4 (GND); also elsewhere on the board

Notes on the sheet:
add led indicators

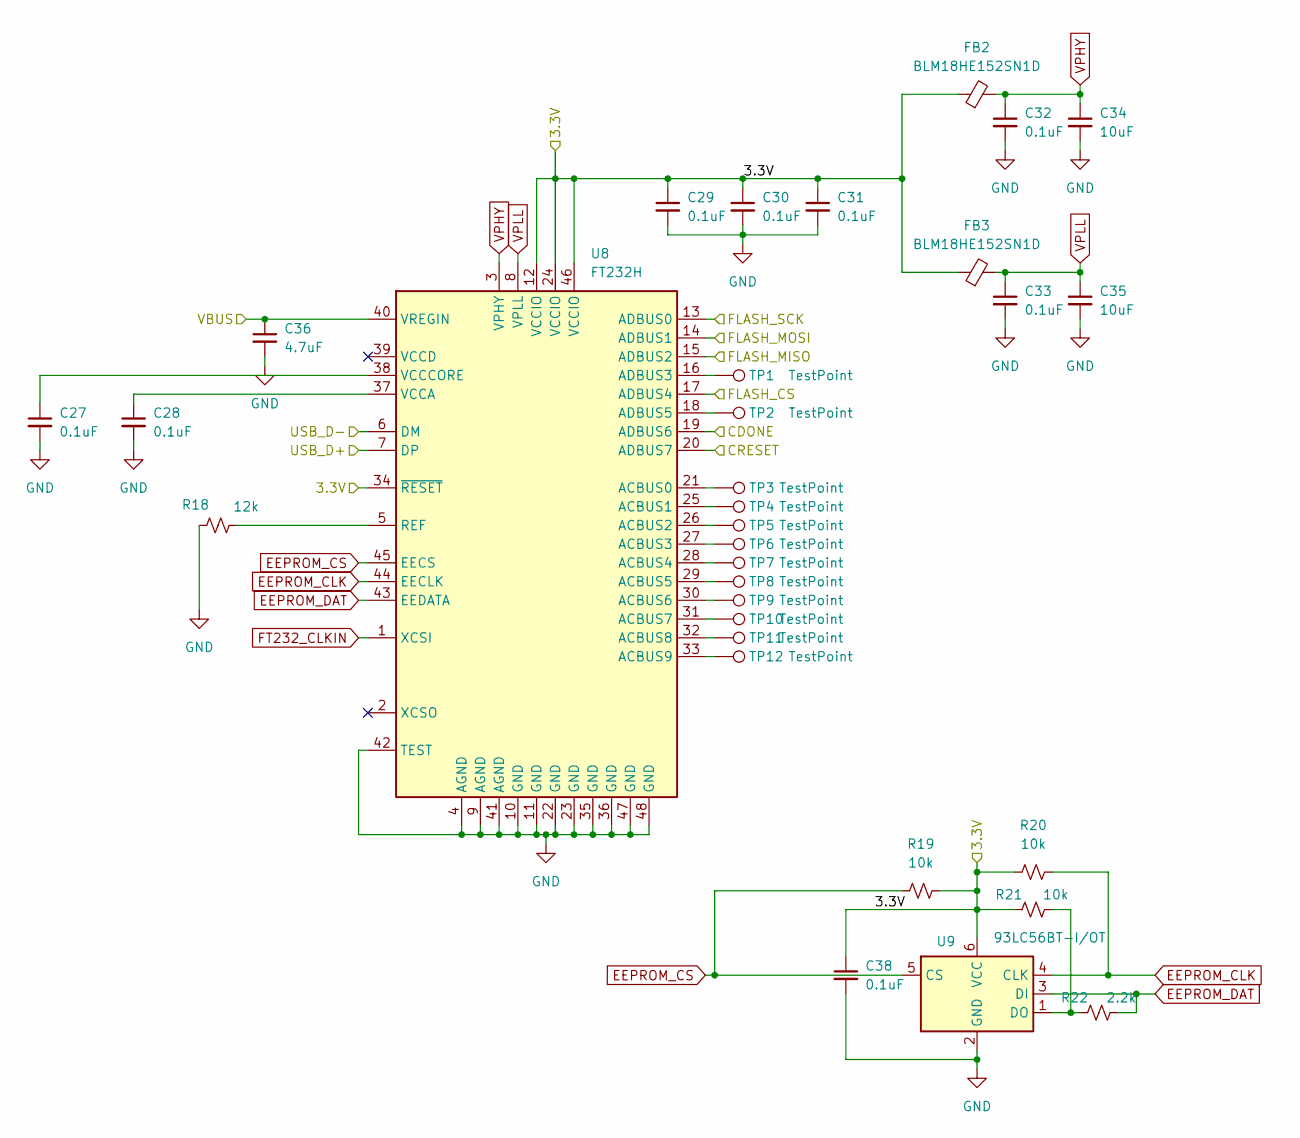
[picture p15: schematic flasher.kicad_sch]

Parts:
C27, C28, C29, C30, C31, C32, C33, C38: 0.1uF; C_0402_1005Metric
C34, C35: 10uF; C_0402_1005Metric
C36: 4.7uF; C_0402_1005Metric
FB2, FB3: BLM18HE152SN1D; L_0603_1608Metric
R18: 12k; R_0402_1005Metric
R19, R20, R21: 10k; R_0402_1005Metric
R22: 2.2k; R_0402_1005Metric
TP1, TP2, TP3, TP4, TP5, TP6, TP7, TP8, TP9, TP10, TP11, TP12: TestPoint; TestPoint_Pad_1.0x1.0mm
U8: FT232H; LQFP-48_7x7mm_P0.5mm
U9: 93LC56BT-I/OT; SOIC-8_3.9x4.9mm_P1.27mm

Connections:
/Config/USB_D+: U8.7 (DP); also elsewhere on the board
/Config/USB_D-: U8.6 (DM); also elsewhere on the board
/FPGA/CDONE: U8.19 (ADBUS6); also elsewhere on the board
/FPGA/CRESET: U8.20 (ADBUS7); also elsewhere on the board
/FPGA/FPGA_SI: U8.15 (ADBUS2); also elsewhere on the board
/FPGA/FPGA_SO: U8.14 (ADBUS1); also elsewhere on the board
/FPGA/FT_CS: U8.17 (ADBUS4); also elsewhere on the board
/FPGA/FT_SCK: U8.13 (ADBUS0); also elsewhere on the board
/Flasher/3.3V: C29.1, C30.1, C31.1, C38.1, FB2.1, FB3.1, R19.2, R20.1, R21.1, U8.12 (VCCIO), U8.24 (VCCIO), U8.34 (~RESET), U8.46 (VCCIO), U9.6 (VCC); also elsewhere on the board
/Flasher/VBUS: C36.1, U8.40 (VREGIN)
EEPROM_CLK: R20.2, U8.44 (EECLK), U9.4 (CLK)
EEPROM_CS: R19.1, U8.45 (EECS), U9.5 (CS)
EEPROM_DAT: R22.2, U8.43 (EEDATA), U9.3 (DI)
FT232_CLKIN: U8.1 (XCSI); also elsewhere on the board
GND: C27.2, C28.2, C29.2, C30.2, C31.2, C32.2, C33.2, C34.2, C35.2, C36.2, C38.2, R18.1, U8.4 (AGND), U8.9 (AGND), U8.10 (GND), U8.11 (GND), U8.22 (GND), U8.23 (GND), U8.35 (GND), U8.36 (GND), U8.41 (AGND), U8.42 (TEST), U8.47 (GND), U8.48 (GND), U9.2 (GND); also elsewhere on the board
unnamed: TP3.1 (1_1), U8.21 (ACBUS0)
unnamed: TP4.1 (1_1), U8.25 (ACBUS1)
unnamed: TP5.1 (1_1), U8.26 (ACBUS2)
unnamed: TP6.1 (1_1), U8.27 (ACBUS3)
unnamed: TP7.1 (1_1), U8.28 (ACBUS4)
unnamed: TP8.1 (1_1), U8.29 (ACBUS5)
unnamed: TP9.1 (1_1), U8.30 (ACBUS6)
unnamed: TP10.1 (1_1), U8.31 (ACBUS7)
unnamed: TP11.1 (1_1), U8.32 (ACBUS8)
unnamed: TP12.1 (1_1), U8.33 (ACBUS9)
unnamed: TP1.1 (1_1), U8.16 (ADBUS3)
unnamed: TP2.1 (1_1), U8.18 (ADBUS5)
unnamed: R18.2, U8.5 (REF)
unnamed: C28.1, U8.37 (VCCA)
unnamed: C27.1, U8.38 (VCCCORE)
unnamed: R21.2, R22.1, U9.1 (DO)
VPHY: C32.1, C34.1, FB2.2, U8.3 (VPHY)
VPLL: C33.1, C35.1, FB3.2, U8.8 (VPLL)

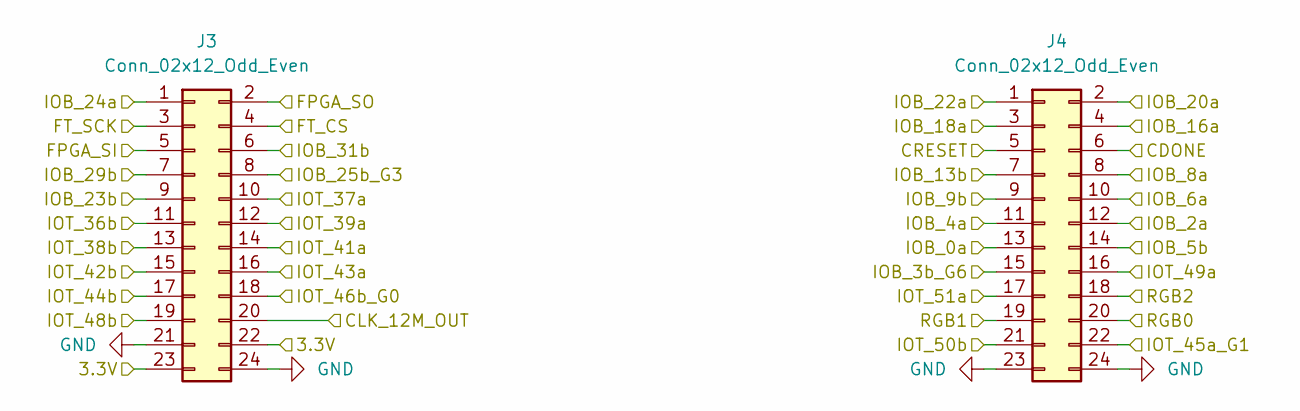
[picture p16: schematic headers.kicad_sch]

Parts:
J3, J4: Conn_02x12_Odd_Even; PinHeader_2x12_P2.54mm_Vertical

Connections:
/Clock/CLK_12M_OUT: J3.20; also elsewhere on the board
/Clock/IOB_25b_G3: J3.8; also elsewhere on the board
/Config/IOB_22a: J4.1; also elsewhere on the board
/Config/IOB_23b: J3.9; also elsewhere on the board
/Config/IOB_24a: J3.1; also elsewhere on the board
/FPGA/CDONE: J4.6; also elsewhere on the board
/FPGA/CRESET: J4.5; also elsewhere on the board
/FPGA/FPGA_SI: J3.5; also elsewhere on the board
/FPGA/FPGA_SO: J3.2; also elsewhere on the board
/FPGA/FT_CS: J3.4; also elsewhere on the board
/FPGA/FT_SCK: J3.3; also elsewhere on the board
/FPGA/IOB_0a: J4.13; also elsewhere on the board
/FPGA/IOB_2a: J4.12; also elsewhere on the board
/FPGA/IOB_3b_G6: J4.15; also elsewhere on the board
/FPGA/IOB_4a: J4.11; also elsewhere on the board
/FPGA/IOB_5b: J4.14; also elsewhere on the board
/FPGA/IOB_6a: J4.10; also elsewhere on the board
/FPGA/IOB_8a: J4.8; also elsewhere on the board
/FPGA/IOB_9b: J4.9; also elsewhere on the board
/FPGA/IOB_13b: J4.7; also elsewhere on the board
/FPGA/IOB_16a: J4.4; also elsewhere on the board
/FPGA/IOB_18a: J4.3; also elsewhere on the board
/FPGA/IOB_20a: J4.2; also elsewhere on the board
/FPGA/IOB_29b: J3.7; also elsewhere on the board
/FPGA/IOB_31b: J3.6; also elsewhere on the board
/FPGA/IOT_36b: J3.11; also elsewhere on the board
/FPGA/IOT_37a: J3.10; also elsewhere on the board
/FPGA/IOT_38b: J3.13; also elsewhere on the board
/FPGA/IOT_39a: J3.12; also elsewhere on the board
/FPGA/IOT_41a: J3.14; also elsewhere on the board
/FPGA/IOT_42b: J3.15; also elsewhere on the board
/FPGA/IOT_43a: J3.16; also elsewhere on the board
/FPGA/IOT_44b: J3.17; also elsewhere on the board
/FPGA/IOT_45a_G1: J4.22; also elsewhere on the board
/FPGA/IOT_46b_G0: J3.18; also elsewhere on the board
/FPGA/IOT_48b: J3.19; also elsewhere on the board
/FPGA/IOT_49a: J4.16; also elsewhere on the board
/FPGA/IOT_50b: J4.21; also elsewhere on the board
/FPGA/IOT_51a: J4.17; also elsewhere on the board
/FPGA/RGB0: J4.20; also elsewhere on the board
/FPGA/RGB1: J4.19; also elsewhere on the board
/FPGA/RGB2: J4.18; also elsewhere on the board
/Flasher/3.3V: J3.22, J3.23; also elsewhere on the board
GND: J3.21, J3.24, J4.23, J4.24; also elsewhere on the board

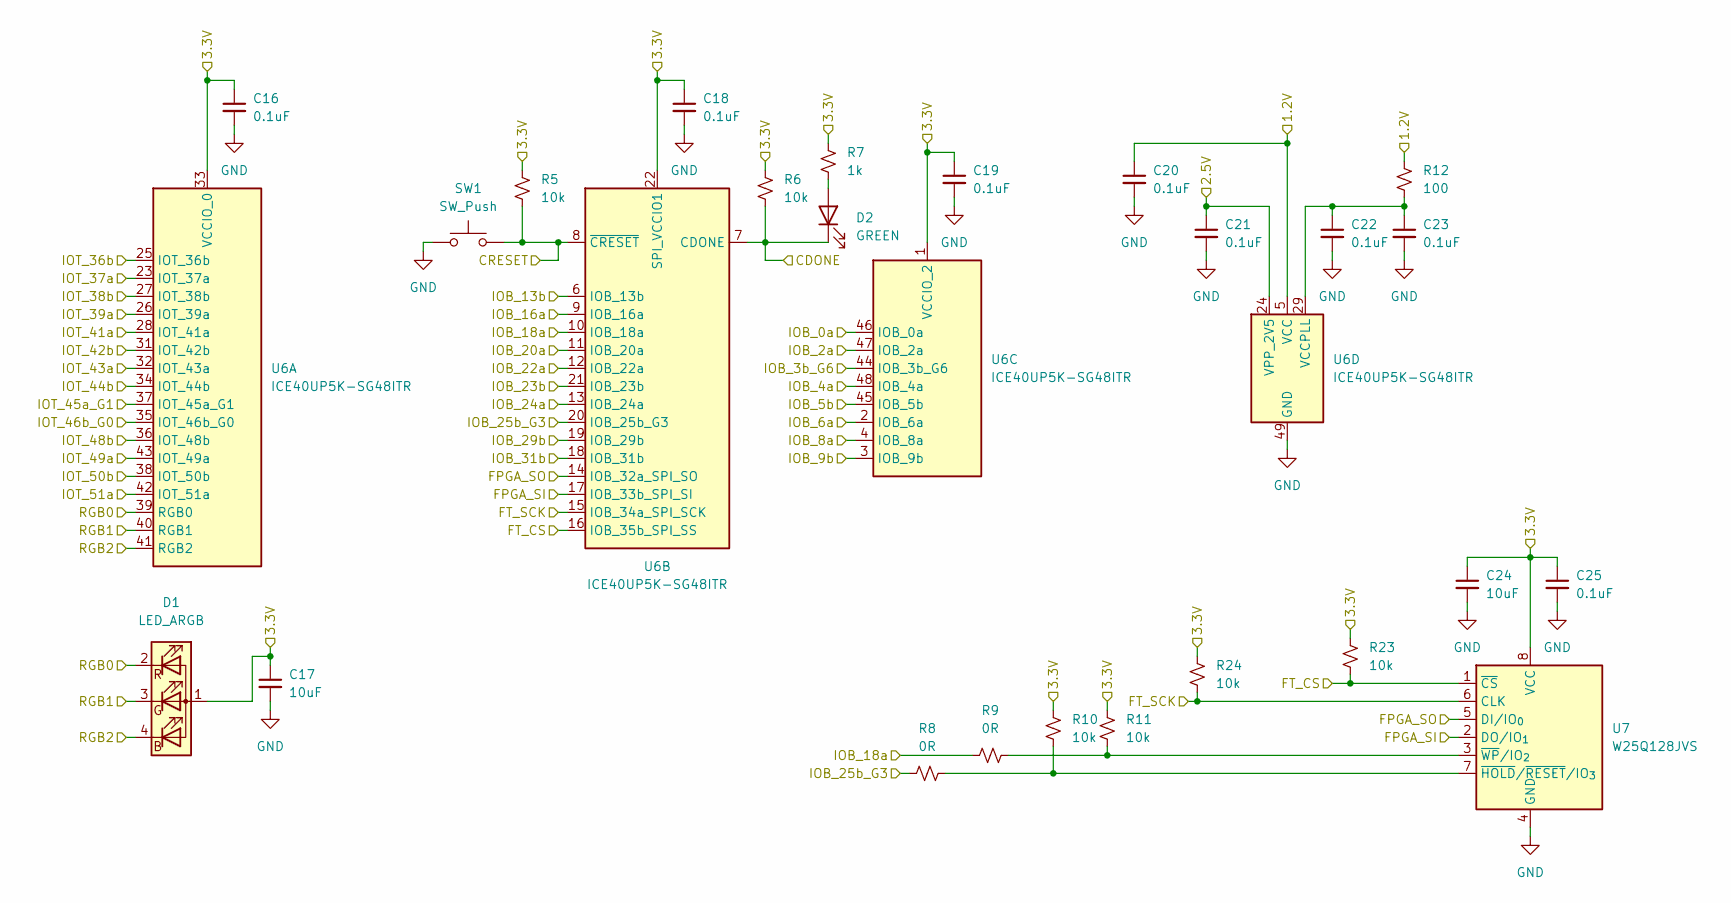
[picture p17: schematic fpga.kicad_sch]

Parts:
C16, C18, C19, C20, C21, C22, C23, C25: 0.1uF; C_0402_1005Metric
C17, C24: 10uF; C_0402_1005Metric
D1: LED_ARGB; LED_Cree-PLCC4_2x2mm_CW
D2: GREEN; LED_0402_1005Metric
R5, R6, R10, R11, R23, R24: 10k; R_0402_1005Metric
R7: 1k; R_0402_1005Metric
R8, R9: 0R; R_0402_1005Metric
R12: 100; R_0402_1005Metric
SW1: SW_Push; Panasonic_EVQPUM_EVQPUD
U6: ICE40UP5K-SG48ITR; QFN-48-1EP_7x7mm_P0.5mm_EP3.5x3.5mm_ThermalVias
U7: W25Q128JVS; SOIC-8_5.3x5.3mm_P1.27mm

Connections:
/Clock/IOB_25b_G3: R8.1, U6.20 (IOB_25b_G3); also elsewhere on the board
/Config/IOB_22a: U6.12 (IOB_22a); also elsewhere on the board
/Config/IOB_23b: U6.21 (IOB_23b); also elsewhere on the board
/Config/IOB_24a: U6.13 (IOB_24a); also elsewhere on the board
/FPGA/1.2V: C20.1, R12.1, U6.5 (VCC), U6.30 (VCC); also elsewhere on the board
/FPGA/2.5V: C21.1, U6.24 (VPP_2V5); also elsewhere on the board
/FPGA/CDONE: D2.1 (K), R6.2, U6.7 (CDONE); also elsewhere on the board
/FPGA/CRESET: R5.2, SW1.2, U6.8 (~CRESET); also elsewhere on the board
/FPGA/FPGA_SI: U6.17 (IOB_33b_SPI_SI), U7.2 (DO/IO_{1}); also elsewhere on the board
/FPGA/FPGA_SO: U6.14 (IOB_32a_SPI_SO), U7.5 (DI/IO_{0}); also elsewhere on the board
/FPGA/FT_CS: R23.2, U6.16 (IOB_35b_SPI_SS), U7.1 (~CS); also elsewhere on the board
/FPGA/FT_SCK: R24.2, U6.15 (IOB_34a_SPI_SCK), U7.6 (CLK); also elsewhere on the board
/FPGA/IOB_0a: U6.46 (IOB_0a); also elsewhere on the board
/FPGA/IOB_2a: U6.47 (IOB_2a); also elsewhere on the board
/FPGA/IOB_3b_G6: U6.44 (IOB_3b_G6); also elsewhere on the board
/FPGA/IOB_4a: U6.48 (IOB_4a); also elsewhere on the board
/FPGA/IOB_5b: U6.45 (IOB_5b); also elsewhere on the board
/FPGA/IOB_6a: U6.2 (IOB_6a); also elsewhere on the board
/FPGA/IOB_8a: U6.4 (IOB_8a); also elsewhere on the board
/FPGA/IOB_9b: U6.3 (IOB_9b); also elsewhere on the board
/FPGA/IOB_13b: U6.6 (IOB_13b); also elsewhere on the board
/FPGA/IOB_16a: U6.9 (IOB_16a); also elsewhere on the board
/FPGA/IOB_18a: R9.1, U6.10 (IOB_18a); also elsewhere on the board
/FPGA/IOB_20a: U6.11 (IOB_20a); also elsewhere on the board
/FPGA/IOB_29b: U6.19 (IOB_29b); also elsewhere on the board
/FPGA/IOB_31b: U6.18 (IOB_31b); also elsewhere on the board
/FPGA/IOT_36b: U6.25 (IOT_36b); also elsewhere on the board
/FPGA/IOT_37a: U6.23 (IOT_37a); also elsewhere on the board
/FPGA/IOT_38b: U6.27 (IOT_38b); also elsewhere on the board
/FPGA/IOT_39a: U6.26 (IOT_39a); also elsewhere on the board
/FPGA/IOT_41a: U6.28 (IOT_41a); also elsewhere on the board
/FPGA/IOT_42b: U6.31 (IOT_42b); also elsewhere on the board
/FPGA/IOT_43a: U6.32 (IOT_43a); also elsewhere on the board
/FPGA/IOT_44b: U6.34 (IOT_44b); also elsewhere on the board
/FPGA/IOT_45a_G1: U6.37 (IOT_45a_G1); also elsewhere on the board
/FPGA/IOT_46b_G0: U6.35 (IOT_46b_G0); also elsewhere on the board
/FPGA/IOT_48b: U6.36 (IOT_48b); also elsewhere on the board
/FPGA/IOT_49a: U6.43 (IOT_49a); also elsewhere on the board
/FPGA/IOT_50b: U6.38 (IOT_50b); also elsewhere on the board
/FPGA/IOT_51a: U6.42 (IOT_51a); also elsewhere on the board
/FPGA/RGB0: D1.2 (RK), U6.39 (RGB0); also elsewhere on the board
/FPGA/RGB1: D1.3 (GK), U6.40 (RGB1); also elsewhere on the board
/FPGA/RGB2: D1.4 (BK), U6.41 (RGB2); also elsewhere on the board
/Flasher/3.3V: C16.1, C17.1, C18.1, C19.1, C24.1, C25.1, D1.1 (A), R5.1, R6.1, R7.1, R10.1, R11.1, R23.1, R24.1, U6.1 (VCCIO_2), U6.22 (SPI_VCCIO1), U6.33 (VCCIO_0), U7.8 (VCC); also elsewhere on the board
GND: C16.2, C17.2, C18.2, C19.2, C20.2, C21.2, C22.2, C23.2, C24.2, C25.2, SW1.1, U6.49 (GND), U7.4 (GND); also elsewhere on the board
unnamed: D2.2 (A), R7.2
unnamed: C22.1, C23.1, R12.2, U6.29 (VCCPLL)
unnamed: R8.2, R10.2, U7.7 (~HOLD/~RESET/IO_{3})
unnamed: R9.2, R11.2, U7.3 (~WP/IO_{2})

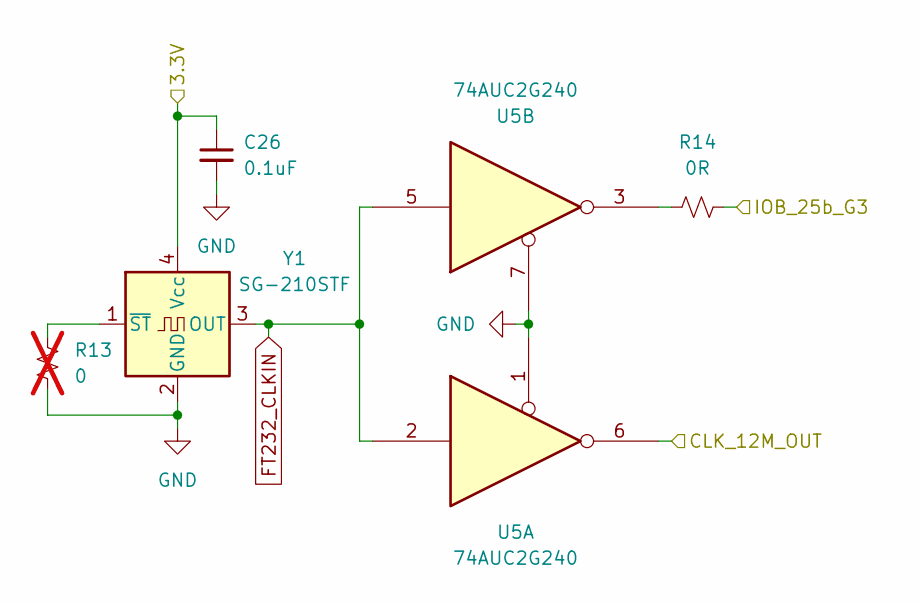
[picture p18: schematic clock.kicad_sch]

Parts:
C26: 0.1uF; C_0402_1005Metric
R13: 0; R_0402_1005Metric; not fitted
R14: 0R; R_0402_1005Metric
U5: 74AUC2G240; VSSOP-8_3x3mm_P0.65mm
Y1: SG-210STF; Oscillator_SMD_SeikoEpson_SG210-4Pin_2.5x2.0mm

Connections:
/Clock/CLK_12M_OUT: U5.6; also elsewhere on the board
/Clock/IOB_25b_G3: R14.2; also elsewhere on the board
/Flasher/3.3V: C26.1, Y1.4 (Vcc); also elsewhere on the board
FT232_CLKIN: U5.2, U5.5, Y1.3 (OUT); also elsewhere on the board
GND: C26.2, R13.2, U5.1, U5.7, Y1.2 (GND); also elsewhere on the board
unnamed: R14.1, U5.3
unnamed: R13.1, Y1.1 (~ST)

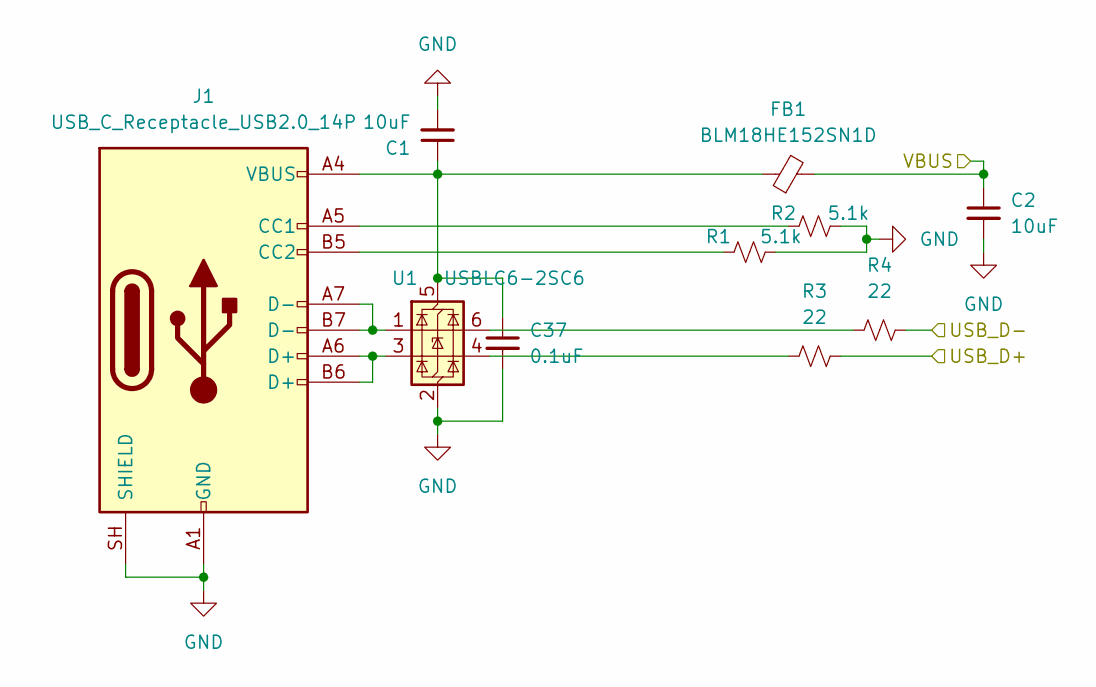
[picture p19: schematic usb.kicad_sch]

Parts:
C1, C2: 10uF; C_0402_1005Metric
C37: 0.1uF; C_0402_1005Metric
FB1: BLM18HE152SN1D; L_0603_1608Metric
J1: USB_C_Receptacle_USB2.0_14P; USB_C_Receptacle_HRO_TYPE-C-31-M-12
R1, R2: 5.1k; R_0402_1005Metric
R3, R4: 22; R_0402_1005Metric
U1: USBLC6-2SC6; SOT-23-6

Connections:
/Config/USB_D+: R3.1; also elsewhere on the board
/Config/USB_D-: R4.1; also elsewhere on the board
/Power/VIN: C2.1, FB1.2; also elsewhere on the board
GND: C1.2, C2.2, C37.2, J1.A1 (GND), J1.A12 (GND), J1.B1 (GND), J1.B12 (GND), J1.SH (SHIELD), R1.1, R2.1, U1.2 (GND); also elsewhere on the board
unnamed: J1.A5 (CC1), R2.2
unnamed: J1.B5 (CC2), R1.2
unnamed: J1.A6 (D+), J1.B6 (D+), U1.3 (I/O2)
unnamed: J1.A7 (D-), J1.B7 (D-), U1.1 (I/O1)
unnamed: R3.2, U1.4 (I/O2)
unnamed: R4.2, U1.6 (I/O1)
unnamed: C1.1, C37.1, FB1.1, J1.A4 (VBUS), J1.A9 (VBUS), J1.B4 (VBUS), J1.B9 (VBUS), U1.5 (VBUS)

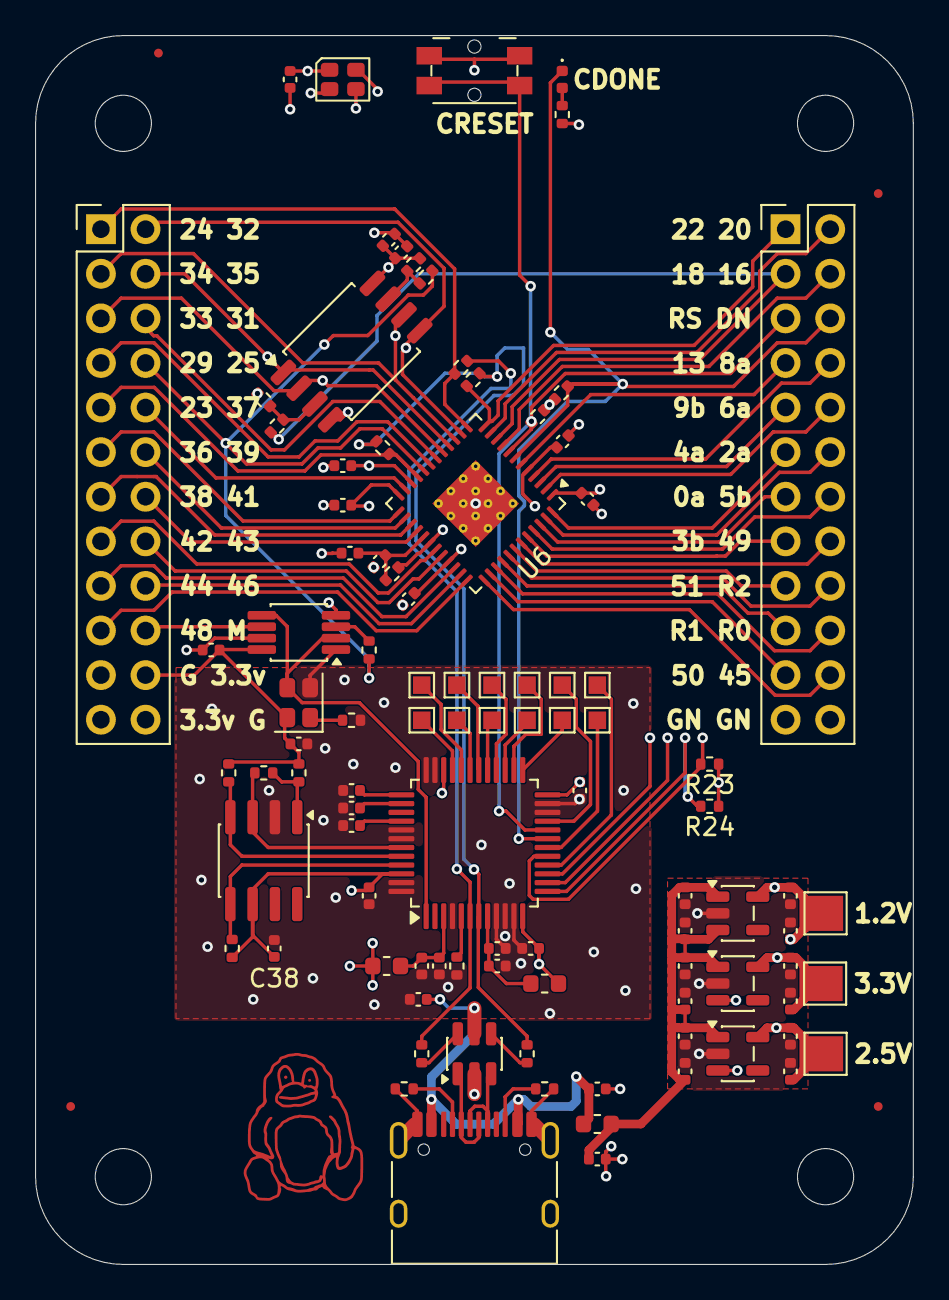
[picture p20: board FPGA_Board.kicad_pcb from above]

Board: 4 copper layers, 50.0 x 70.0 mm, 104 parts (0 on the bottom side), 85 nets.

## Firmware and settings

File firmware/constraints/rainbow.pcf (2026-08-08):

# Pin constraints for the FPGA_Board (ICE40UP5K-SG48, 12 MHz reference)
# Package pin numbers confirmed from the KiCad netlist (2026-08-08).

set_io clk_12m 20    # IOB_25b_G3  - 12 MHz clock (via 74AUC2G240 buffer)
set_io rgb_r  39     # RGB0        - red   cathode (open-drain, active low)
set_io rgb_g  40     # RGB1        - green cathode (open-drain, active low)
set_io rgb_b  41     # RGB2        - blue  cathode (open-drain, active low)

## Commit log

2026-08-08 finish schematic and almost done pcb routing
    [FPGA_Board.kicad_pcb, FPGA_Board.kicad_sch, clock.kicad_sch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]
2026-08-08 add images and render
    [FPGA_Board.kicad_pcb, FPGA_Board.kicad_sch, flasher.kicad_sch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]
2026-08-09 add production files
    [bom.csv, designators.csv, positions.csv]
2026-08-18 update bom and journal
    [BOM.csv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]
2026-09-22 journal adds
    [FPGA_Board.kicad_pcb]
